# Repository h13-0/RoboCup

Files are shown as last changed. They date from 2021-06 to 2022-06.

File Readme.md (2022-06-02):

# RoboCup 2021 助老机器人赛道
中国机器人大赛国一(冠军)实现。  
由于本文档中有较多图片注释, 因此国内用户阅读本文档时应注意使用上网工具后再进行阅读。  
# 获奖证书
<details>
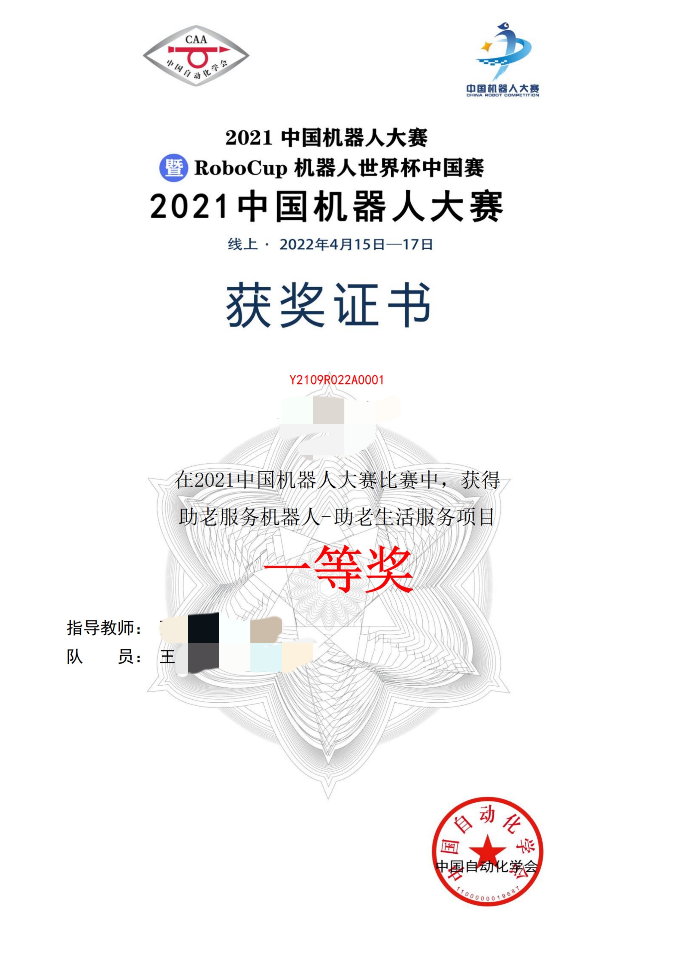
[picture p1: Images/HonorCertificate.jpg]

</details>

# 使用本仓库
如果需要更改代码, 则建议直接fork本仓库。  
## 克隆建议:
由于本仓库已经拆分出多个子模块, <strong><font color='red'>直接下载zip会造成缺少子模块的情况。</font></strong>  
如需复现本项目, 则<strong><font color='red'>必须</font></strong>使用git完成。  
git clone时需使用以下命令:  
```Powershell
git clone https://github.com/h13-0/RoboCup.git
git submodule update --init
```

# 渲染图
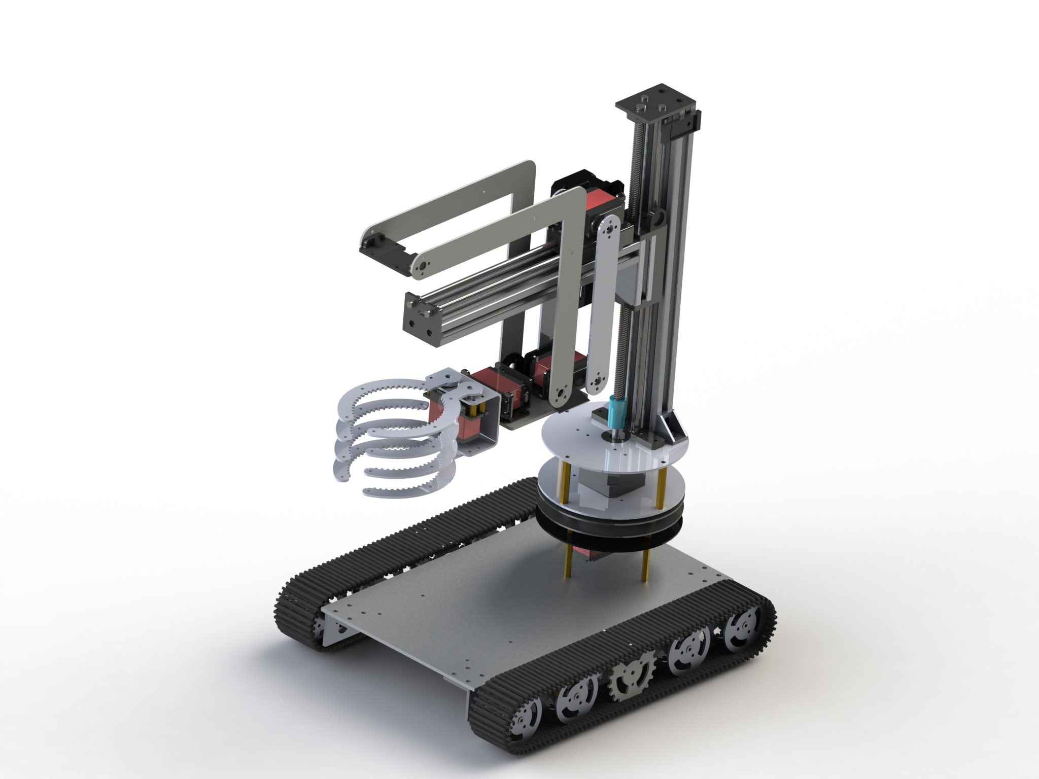
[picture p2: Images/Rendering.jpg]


# 项目构成
本项目主要分为三个板块:  
1. STM32板块
2. 图像处理板块
3. 机械设计

## STM32板块
参考:  
[STM32](./STM32/)  

## 图像处理板块
参考:  
[图像处理](./ImageProcessing)  

## 机械设计
参考:  
[机械设计](./Machine/)

## 上位机调参
上位机使用[VOFA+](https://www.vofa.plus/)
配置文件见[VOFAConfig](/HostComputer/VOFAConfig/)

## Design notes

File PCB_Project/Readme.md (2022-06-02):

# PCB工程  
[机器人PCB](./RobotPCB)  
[Air724UG转接板](./Air724_Module)  
(Air724UG转接板的TX RX好像画反了)

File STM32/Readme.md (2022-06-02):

# STM32
本部分负责机器人除图像处理以外的所有流程控制部分。  
本程序采用LL库, 底层使用CubeMX生成, 其他层由CubeIDE编写。  
如需复现此项目, 请自行安装[STM32CubeMX](https://www.st.com/zh/development-tools/stm32cubemx.html)和[STM32CubeIDE](https://www.st.com/en/development-tools/stm32cubeide.html)。  

## 为什么不用STP和Keil?
Keil的编译器过于老旧, 在实际使用中遇到了一些BUG, 并且stp(标准库)不再支持STM32F7、STM32G0等新产品。  
而LL效率和stp相当甚至更优, 写法相似, 故迁移至LL进行编写。  

## 程序移植
你只需要重新实现 `Platform` 文件夹中全部的函数即可。  
即使你使用的是Hal库或者标准库, 只要STM32和C语言过关, 就不存在任何问题。  
~~即如果您无法从LL移植到Hal或者标库，不是本项目的问题。~~  

<details>
<summary>代码结构</summary>
程序分为应用层, 驱动层, 底层。各层之间解耦合。  
应用层只能通过 `Platform/ports.h` 调用驱动层。  
驱动层只能通过 `Platform/xx.h` 调用底层。  
为了考虑整体移植性, 降低了部分驱动层使用简洁性。  

如无特殊需求, 只需要修改 `App.c` 文件即可实现比赛全流程。  

程序结构:  
```
STM32:
│  .cproject 
│  .project                                 -> 项目文件, 使用STM32CubeIDE打开本文件即可。
│  STM32.ioc                                -> CubeMX配置文件, 使用CubeMX打开本文件进行底层配置。
│  STM32F103RCTX_FLASH.ld
│
├─Drivers                                   -> [ST库文件]
│  ├─CMSIS                                  -> [ST库文件] CMSIS
│  │
│  └─STM32F1xx_HAL_Driver                   -> [ST库文件] STM32的Hal和LL库文件
│
├─Images
│  ├─ChineseFonts                           -> [资源文件] 隶书汉字字模, 字模转换用
│  │      *.bmp
│  │
│  └─SchoolMotto                            -> [资源文件] 校训图, 字模转换用
│          SchoolMotto.bmp
│
├─Inc
│
├─Src
│  │  main.c
│  │  PrivateConfigs.h                      -> [配置文件] 隐私相关配置文件, 如电话号码, 已gitignore。
│  │  RobotConfigs.h                        -> [配置文件] 机器人全局配置文件。
│  │  stm32f1xx_hal_msp.c
│  │  stm32f1xx_it.c                        -> [中断管理] 中断表。
│  │  syscalls.c
│  │  sysmem.c
│  │  system_stm32f1xx.c
│  │
│  ├─App                                    -> [应用层]
│  │  │  App.c                              -> **比赛主要逻辑流程**
│  │  │  App.h
│  │  │
│  │  ├─AppLog                              -> Log库实现
│  │  │  │  AppLog.c
│  │  │  │  AppLog.h
│  │  │  │
│  │  │  └─JustFloat                        -> VOFA 上位机的 `JustFloat` 协议实现
│  │  │          JustFloat.c
│  │  │          JustFloat.h
│  │  │
│  │  ├─ArmControl                          -> 机械臂控制库
│  │  │      ArmControl.h
│  │  │      LiftingPlatform.c              -> 升降台机械臂控制实现
│  │  │      LiftingPlatform.h
│  │  │      MechanicalArm.c                -> 传统机械臂控制实现
│  │  │
│  │  ├─Debug
│  │  │  │  Debug.c                         -> 将串口中断信息整理到`ParameterAdjust`中
│  │  │  │  Debug.h
│  │  │  │
│  │  │  └─ParameterAdjust                  -> 参数调节器
│  │  │          ParameterAdjust.c
│  │  │          ParameterAdjust.h
│  │  │
│  │  ├─Examples                            -> [Examples] 本文件夹下为调用App、Driver、Platform层的函数Demo以及赛题要求的子步骤函数实现。
│  │  │      AllInit.c                      -> [赛题实现] 初始化所有软硬件的Demo
│  │  │      AllInit.h
│  │  │      AngleSensorTest.c              -> [Demo] 测试陀螺仪偏航角的实现
│  │  │      AngleSensorTest.h
│  │  │      BluetoothTest.c                -> [赛题实现] 赛题所要求的蓝牙相关功能
│  │  │      BluetoothTest.h
│  │  │      BroadcastIdentifyResult.c      -> 使用语音播报水果识别结果的实现
│  │  │      BroadcastIdentifyResult.h
│  │  │      CatchApple.c                   -> [赛题实现] 抓取苹果的实现
│  │  │      CatchApple.h
│  │  │      CatchTrashCan.c                -> [赛题实现] 抓取垃圾桶的实现
│  │  │      CatchTrashCan.h
│  │  │      DisplayResult.c                -> [赛题实现] 将识别结果显示在显示屏上的实现
│  │  │      DisplayResult.h
│  │  │      DisplaySchoolMotto.c           -> [赛题实现] 显示校训
│  │  │      DisplaySchoolMotto.h
│  │  │      EmptyTrash.c                   -> [赛题实现] 清空垃圾桶的实现
│  │  │      EmptyTrash.h
│  │  │      Examples.h                     -> [接口文件] 所有Example的头文件
│  │  │      IdentifyFruit.c                -> [赛题实现] 识别水果的实现
│  │  │      IdentifyFruit.h
│  │  │      PlaceApple.c                   -> [赛题实现] 放置水果的实现
│  │  │      PlaceApple.h
│  │  │      PlaceTrashCan.c                -> [赛题实现] 放置垃圾桶的实现
│  │  │      PlaceTrashCan.h
│  │  │      PrepareArmPosition.c           -> [赛题实现] 使机械臂进入准备状态
│  │  │      PrepareArmPosition.h
│  │  │      SendResultViaMessage.c         -> [赛题实现] 将识别结果通过短信发送到指定手机
│  │  │      SendResultViaMessage.h
│  │  │      ThrowApple.c                   -> [赛题实现] 扔苹果
│  │  │      ThrowApple.h
│  │  │      WashApple.c                    -> [赛题实现] 洗苹果
│  │  │      WashApple.h
│  │  │
│  │  ├─FastMatch                           -> [协议解析] 一个简单协议解析器
│  │  │      FastMatch.h
│  │  │
│  │  ├─MotionControl                       -> [运动控制] 运动控制实现
│  │  │      MotionControl.c
│  │  │      MotionControl.h
│  │  │
│  │  ├─PID                                 -> [PID] PID算法实现
│  │  │      PID.c
│  │  │      PID.h
│  │  │
│  │  ├─Timer                               -> [定时器] 系统框架定时器
│  │  │      Timer.c
│  │  │      Timer.h
│  │  │
│  │  ├─TOF
│  │  ├─UI                                  -> [UI] 简单UI实现
│  │  │      DrawPicture.c                  -> 绘制图像
│  │  │      DrawPicture.h
│  │  │      DrawText.c                     -> 绘制文本
│  │  │      DrawText.h
│  │  │      OfficialScriptChineseFont.c    -> 隶书汉语字体库
│  │  │      OfficialScriptChineseFont.h
│  │  │      SchoolMotto.c                  -> 校训图片库
│  │  │      SchoolMotto.h
│  │  │      UI.h                           -> UI接口文件
│  │  │
│  │  └─VoicePlayer                         -> [VoicePlayer] 语音播报框架
│  │          VoicePlayer.c
│  │          VoicePlayer.h
│  │
│  ├─Drivers                                -> [驱动层]
│  │  │  Drivers.c                          -> 驱动层初始化API实现
│  │  │  Drivers.h
│  │  │
│  │  ├─Bluetooth                           -> [Driver] HC-05蓝牙驱动
│  │  │      Bluetooth.c
│  │  │      Bluetooth.h
│  │  │
│  │  ├─DF_PlayerMini                       -> [Driver] DF Player Mini 语音播放器驱动
│  │  │      DF_PlayerMini.c
│  │  │      DF_PlayerMini.h
│  │  │
│  │  ├─Encoder                             -> [Driver] 编码器驱动
│  │  │      Encoder.c
│  │  │      Encoder.h
│  │  │
│  │  ├─ImageProcessingModule               -> [Driver] 图像处理模块驱动(即协议解析器)
│  │  │      ImageProcessingModule.c
│  │  │      ImageProcessingModule.h
│  │  │
│  │  ├─INA219                              -> [Driver] INA219电流传感器驱动
│  │  │      INA219.c
│  │  │      INA219.h
│  │  │
│  │  ├─Luat                                -> [Driver] Air724UG 4G 模块AT驱动
│  │  │      Luat.c
│  │  │      Luat.h
│  │  │
│  │  ├─Motor                               -> [Driver] H桥电机驱动板驱动
│  │  │      Motor.c
│  │  │      Motor.h
│  │  │
│  │  ├─Servo                               -> [Driver] 舵机驱动
│  │  │      Servo.c
│  │  │      Servo.h
│  │  │
│  │  ├─SimpleProtocolPraise                -> [Driver] 简单协议解析器
│  │  │      SimpleProtocolPraise.h
│  │  │
│  │  ├─SKTOF                               -> [Driver] SK TOF 驱动
│  │  │      SKTOF.c
│  │  │      SKTOF.h
│  │  │
│  │  ├─SSD1283                             -> [Driver] SSD1283 屏幕驱动
│  │  │      SSD1283.c
│  │  │      SSD1283.h
│  │  │
│  │  ├─Stepper                             -> [Driver] 步进驱动
│  │  │      Stepper.c
│  │  │      Stepper.h
│  │  │
│  │  ├─VL6180X                             -> [Driver] VL6180X 短距离TOF 驱动
│  │  │  ├─Core
│  │  │  │      vl6180x_api.c
│  │  │  │      vl6180x_api.h
│  │  │  │      vl6180x_cfg.h
│  │  │  │      vl6180x_def.h
│  │  │  │      vl6180x_i2c.c
│  │  │  │      vl6180x_i2c.h
│  │  │  │
│  │  │  └─Platform
│  │  │          vl6180x_easy_api.c         -> [Driver] VL6180X 驱动简易接口实现
│  │  │          vl6180x_easy_api.h
│  │  │          vl6180x_platform.c
│  │  │          vl6180x_platform.h
│  │  │          vl6180x_types.h
│  │  │
│  │  └─WT101                               -> [Driver] WT101 陀螺仪 驱动
│  │          WT101.c
│  │          WT101.h
│  │
│  └─Platform                               -> 底层, 用于适配LL库。如果想要移植到Hal库或标准库, 请关注本文件夹。
│      │  ports.c                           -> [Platform] 底层初始化API实现
│      │  ports.h
│      │
│      ├─Clock                              -> [Platform] 系统时钟实现。
│      │      Clock.c
│      │      Clock.h
│      │      Readme.md
│      │
│      ├─EncoderPorts                       -> [Platform] 编码器底层接口。
│      │      Encoder.md
│      │      EncoderPorts.c
│      │      EncoderPorts.h
│      │
│      ├─GPIO                               -> [Platform] GPIO底层接口。
│      │      GPIO.c
│      │      GPIO.h
│      │
│      ├─I2C                                -> [Platform] I2C底层接口。
│      │      I2C.c
│      │      I2C.h
│      │
│      ├─Interrupts                         -> [Platform] 中断底层接口。
│      │  │  Interrupts.h
│      │  │
│      │  ├─ExternalInterrupts              -> [Platform] 外部中断
│      │  ├─TimerInterrupts                 -> [Platform] 定时器中断
│      │  │      TimerInterrupts.c
│      │  │      TimerInterrupts.h
│      │  │
│      │  └─USARTInterrupts                 -> [Platform] 串口中断
│      │          USARTInterrupts.c
│      │          USARTInterrupts.h
│      │
│      ├─PWM                                -> [Platform] PWM底层实现
│      │      PWM.c
│      │      PWM.h
│      │
│      ├─SPI                                -> [Platform] SPI底层实现
│      │      SPI.c
│      │      SPI.h
│      │
│      └─USART                              -> [Platform] 串口底层实现
│              USART.c
│              USART.h
│
├─Startup
│      startup_stm32f103rctx.s
│
└─Voices                                    -> [资源文件] 语音播报原素材, 请使用本文件下的素材文件进行播报。
        00*.mp3
```
</details>

# 电路图  
[电路图](../PCB_Project/)  

# 硬件选择
如您需要复现本项目, 建议使用STM32F103RC以上的型号, 由于串口数量原因, 不建议使用本项目所使用的的STM32F103RCT6。  
本项目所有重要模块的开发文档均已上传至[Docs](../Docs/)  
## 陀螺仪
陀螺仪选型为WT101, 经过测试, MPU9250不满足需求。  

## 激光测距
### 主激光
SK-Z-20 串口激光测距。  
### 机械臂闭环激光
由于本结构机械臂坐标系解算控制精度已达标, 因此项目中未使用, 推荐VL6180X。  

## 显示屏
SSD1283半反半透屏, 特性是阳光下清晰可见。  

## 4G模块
[合宙Air724UG](https://www.openluat.com/product_center/product_detail?id=12)  
2020年年初价格: 19.9元一张核心板一张开发板。  

## 电流检测
通过检测机械爪舵机电流来检测机械爪是否成功抓到物体。  
可以使用图像识别模块代替, 本项目中未使用。  

## 蓝牙模块
HC-05  

## 电机驱动(H桥)
298NAD  

## 电机
1:30减速比, 100线正交光电码盘, 转速280。  

## 定时器  
定时器选择请参考STM32CubeMX配置文件。  

## 舵机
舵机命名参考: 
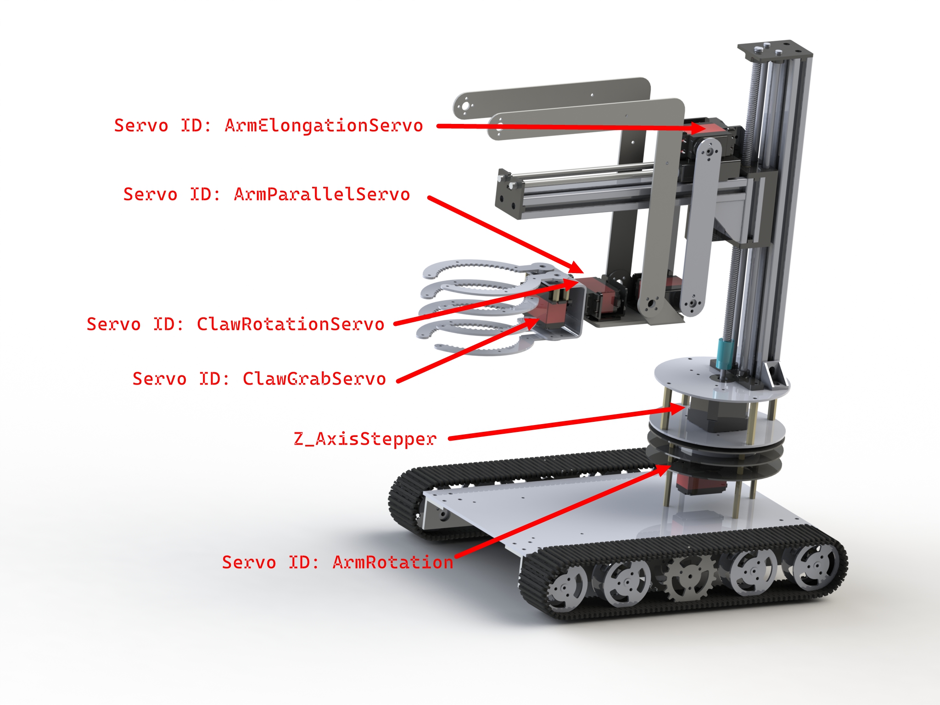
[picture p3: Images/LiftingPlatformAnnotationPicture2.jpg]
  
舵机选型(以`LiftingPlatform`为准):  
| Servo ID | Model |  
| --- | --- |
| ArmRotationServo | TD8120MG 270° |  
| ArmElongationServo | DS3235MG 180° |  
| ArmParallelServo | DS3230MG 180° |  
| ClawRotationServo  | TD8120MG 180° |  
| ClawGrabServo | TBSN-K15 180° |  

> Note:  
> MG为数字舵机, SG为模拟舵机。  

## 串口调参
接口: USART1  
波特率: 1152000  
上位机使用[VOFA+](https://www.vofa.plus/)  
参考: [HostComputer](../HostComputer/VOFAConfig/Readme.md)  

### 图像处理模块  
使用RK3328+RK1808S0计算棒, 推荐替换为RK3568.  
#### 图像处理部分参考    
[图像处理](../ImageProcessing/Readme.md)  
[通信协议](../ImageProcessing/Protocol.md)

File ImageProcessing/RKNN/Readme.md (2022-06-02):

# 程序架构
文件结构:  
```
RKNN/Code:
│  Logo.jpg
│  
│  Readme.md
│
├─FrameBufferMonitor
│
├─Images
│
├─TargetDetector
│
├─WorkingFlow
│
└─YoloDetector
```

`Logo.jpg`           为启动时显示的Logo  
`main.py`            为入口函数, 随后调用`WorkingFlow/MainWorkingFlow.py`  
`FrameBufferMonitor` 将图像越过Linux的UI层直接输出到屏幕的代码实现, **注意不能使用桌面模式，只能使用命令行模式(即initlevel为3而不是5)**  
`Images`             程序STM32控制程序拍照后, 图片保存的目录  
`TargetDetector`     基于HSV的靶标检测  
`WorkingFlow`        主要工作流程实现  
`YoloDetector`       RKNN的YOLO V4 Tiny实现  

## FrameBufferMonitor
具体linux的`FrameBuffer`是什么请自行百度。  
该实现使用C++和Python混合编程, C++实现详见对应src文件夹。  
如果项目所提供的[libframebuffer.so](./Code/FrameBufferMonitor/lib/libframebuffer.so)无法使用, 请自行搭建`OpenCV`环境重新编译。  
```Bash
cd ImageProcessing/RKNN/Code/FrameBufferMonitor
chomd 777 ./build.sh
./build.sh
```
如遇到错误, 请自行检查OpenCV环境。  

### 调用方式
比较简单, 建议直接查看[FrameBufferMonitor.py](./Code/FrameBufferMonitor/FrameBufferMonitor.py)源码。  

## Images
文件命名方式: `时间戳.jpg`。  
本功能是为了方便调节靶标的HSV色域提供的方法。  
在STM32程序中的[PlaceApple.c](../../STM32/Src/App/Examples/PlaceApple.c#L112)中有所调用。  
`STM32/Src/App/Examples/PlaceApple.c Line 112`
```C
TakeSnapShot();
```

## TargetDetector
本方案采用HSV进行实现。  
为方便调参, 本项目实现了一个HSV调参工具: [HSV_Range](https://github.com/h13-0/HSV-Range)  
参数较为简单, 建议直接阅读源码: [TargetDetector.py](./Code/TargetDetector/TargetDetector.py)  
值得注意的是, 本参数仅适用于固定的靶标和**固定的分辨率(640, 320)**  

## WorkingFlow
参数较多但简单, 看源码吧。  

## YoloDetector
模型文件需要从`Darknet`转换到`rknn`, 参考: [tools](../YoloV4Tiny/tools/Readme.md)  

# 环境配置
有以下几种方案(按推荐顺序排序):  
1. [RKNN_Lite](https://github.com/rockchip-linux/rknn-toolkit/tree/master/rknn-toolkit-lite/packages)
2. [直接使用Archiconda部署](./Environment/RK3328_env/Readme.md)
3. [ROC-RK3328-CC镜像部署](./Environment/ROC-RK3328-CC-Images/Readme.md)

本文件夹下所有文件的下载链接:  
> 链接：https://pan.baidu.com/s/1-s8oynvUIC-BW_bOgdHDag?pwd=heop  
> 提取码：heop

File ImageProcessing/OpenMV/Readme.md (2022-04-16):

**已废弃, 不要使用。 建议使用YoloV4Tiny.**

# OpenMV水果识别部分

## 串口通信
### STM32 -> OpenMV
```

```

### OpenMV -> STM32
```

import struct
usart = UART(3, 115200)
msgPack = struct.pack("<ffbbbb", float((r[0] + r[2]) / 400.0), float((r[1] + r[3]) / 240.0), 0x00, 0x00, 0x80, 0x7f)
usart.write(msgPack)
```

## Cascade级联分类器实现

### 制作数据集

### 打包数据集
```
opencv_createsamples.exe -info E:\project\RoboCup\OpenMV\CascadeClassifier\Resized\Apple\List.txt -vec apple.vec -bg E:\project\RoboCup\OpenMV\CascadeClassifier\Background\List.txt -num 151 -w 32 -h 32
```

### 训练
```
mkdir xml
C:\Users\h13\Documents\OpenCVCascade\opencv_traincascade.exe -data xml -vec .\apple.vec -bg E:\project\RoboCup\OpenMV\CascadeClassifier\Background\List.txt -numPos 120 -numNeg 151 -numStages 17 -featureType haar -w 32 -h 32
```

### 转换二进制文件
```
python.exe .\cascade_convert.py .\cascade.xml
```

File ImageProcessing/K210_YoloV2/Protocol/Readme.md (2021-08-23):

# Usage
Copy Floder `` to Disk
```
from Protocol.Protocol import BinaryProtocol
import time

protocol = BinaryProtocol(115200)

while True:
    packet = protocol.GetNewPacket()
    while(packet != None):
        p = protocol.MatchFloat(packet, "AP:")
        if(p != None):
            print(p)
        packet = protocol.GetNewPacket()
    time.sleep(0.5)
```

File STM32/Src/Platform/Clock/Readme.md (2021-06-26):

# CubeMX配置
System Core -> NVIC
    -> Code generation
        -> Time base: System tick timer
            -> Cancel "Call HAL handler" 

# 使用
1. 将 `void SysTickInterruptHandler(void)` 放到 `stm32f1xx_it.c` 中的 `void SysTick_Handler(void)` 中。
2. 调用 `ClockInit()` 。

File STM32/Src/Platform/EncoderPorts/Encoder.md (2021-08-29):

# CubeMX配置
TIMx -> Combined Channels -> Encoder Mode
     -> Parameter Settings -> Encoder -> Encoder Mode -> Encoder Mode Tl1 (只记录上升沿)
                                      -> Polarity -> Rising Edge

GPIO -> TIM -> PXx -> GPIO Pull-up/Pull-down -> Pull-down

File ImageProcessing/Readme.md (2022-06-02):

# 水果种类  
1. 苹果
2. 香梨
3. 橘子
4. 雪梨
5. 柠檬
6. 桃子
7. 香蕉
8. 火龙果
9. 猕猴桃
水果模型图参考[水果模型](../Docs/2021%E4%B8%AD%E5%9B%BD%E6%9C%BA%E5%99%A8%E4%BA%BA%E5%A4%A7%E8%B5%9B-%E5%8A%A9%E8%80%81%E6%9C%8D%E5%8A%A1%E6%9C%BA%E5%99%A8%E4%BA%BA(%E5%8A%A9%E8%80%81%E7%94%9F%E6%B4%BB%E6%9C%8D%E5%8A%A1)-%E6%B0%B4%E6%9E%9C%E6%A8%A1%E5%9E%8B.pdf)  

# 通信协议  
[Protocol](/ImageProcessing/Protocol.md)  

# 识别方案
## YoloV4Tiny
效果最好, 但是算力要求较高。  
建议部署于RK1808或RK3568等平台上。  
使用[Darknet](https://github.com/AlexeyAB/darknet)进行训练。  
可识别内容仅限于上述9种水果, 不包括靶标。  
靶标建议使用HSV色块识别。  
训练集:  
> 链接：https://pan.baidu.com/s/13T8VhDXatusKtdSlCLSglQ?pwd=kcy0  
> 提取码：kcy0  

## HSV色块识别  
**不建议用于水果识别, 可用于靶标识别**  
[HSV水果识别实现](./HSV/RoboCupImageProcessing/)  
HSV调参工具: [HSV-Range](https://github.com/h13-0/HSV-Range)  

# 最终方案  
使用YoloV4Tiny进行水果识别, 利用`RKNN_Lite`部署于RK1808计算棒上, HSV进行靶标识别。  
最终方案见: [RKNN](./RKNN/)

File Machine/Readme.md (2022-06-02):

# 渲染图
  

# 实拍图


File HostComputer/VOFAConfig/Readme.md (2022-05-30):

# 上位机文档
上位机使用[VOFA+](https://www.vofa.plus/)  
UI配置文件, 命令配置文件均在本文件夹下, 请自行研究。

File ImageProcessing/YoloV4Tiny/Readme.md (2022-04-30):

# 炼丹方法
取海量残次丹药置于炉内, 水入洗之, 置于器内熬至百沸。  
再取结晶之物, 置于新炉, 加入上好佐料, 文火慢炖, 则丹药始成。  

<details>
<summary>详细做法</summary>
下载并解压[数据集](/http)  
先使用自动打标生成的数据集`yolomark`(由于数据集分布和实际情况有所出入, 且训练集验证集分布过于相似导致严重过拟合, 所以直接训练下来的模型的种类识别几乎完全错误, 但是方框是准的)  
然后保留自动打标生成的模型使用实际手动拍摄制作的数据集`yolomarkRealScene`再次进行训练即可。  

</details>

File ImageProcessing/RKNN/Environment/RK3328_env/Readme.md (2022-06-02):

# RK3328 RKNN_Lite 环境  
## 安装方法  
**可能**只能在[Firefly的ROC-RK3328-CC](https://www.t-firefly.com/product/rocrk3328cc.html)板子的[Ubuntu18.04](https://www.t-firefly.com/doc/download/34.html#other_68)的`ROC-RK3328-CC-UBUNTU18.04-GPT-20200730-1744.img`系统上使用，其他aarch64的Ubuntu18.04等系统上**可能**也可以使用，具体取决于`GLIBC`等系统底层依赖版本。  
**尽量将Archiconda安装到**`/opt/Archiconda/`下，然后将本文件夹解压到`/opt/Archiconda/RKNN_Lite`下，然后按照百度加载环境即可。  

`archiconda_RKNN_Lite.7z`下载链接:  
> 链接：https://pan.baidu.com/s/1-s8oynvUIC-BW_bOgdHDag?pwd=heop  
> 提取码：heop

## 使用方法
参考文档：[RKNN](../../Readme.md)

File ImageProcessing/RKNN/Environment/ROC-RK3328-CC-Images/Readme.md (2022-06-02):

# ROC-RK3328-CC镜像备份
## 使用方法
购买[ROC-RK3328-CC](https://www.t-firefly.com/product/rocrk3328cc.html)和[RK1808S0](https://t.rock-chips.com/portal.php?mod=view&aid=28), 使用[balenaEtcher](https://www.balena.io/etcher/)将`ROC-RK3328-CC.7z`刷入大于等于16G的内存卡中即可使用。  

## 下载链接
`ROC-RK3328-CC.7z`下载链接:  
> 链接：https://pan.baidu.com/s/1-s8oynvUIC-BW_bOgdHDag?pwd=heop  
> 提取码：heop

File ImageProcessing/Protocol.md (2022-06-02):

# 通信协议  
**物理接口采用串口, 波特率115200, 建议配合DMA使用**  

基础协议为二进制小端通信, 基础协议结构:  
`${Key}:${HexValue}`  
**`${HexValue}` 表示小端模式的二进制信息。**  

## 协议表:  
### STM32 -> Module:  
#### 命令  
Key = `CMD`  
Type = string  
| Key | Value | 作用 |
| --- | --- | --- |
| CMD | `AppleDetectLeft` | 检测左侧水果 |
| CMD | `FruitIdentify` | 检测水果数量和种类 |
| CMD | `TargetDetection` | 检测靶标位置 |

### Module -> STM32:  
#### 工作模式  
Key = `WM`  
Type = uint8_t  
| Value | Mode |
| ----- | --- |
| 0 | Standby |
| 1 | AppleDetectMax |
| 2 | AppleDetectLeft  |
| 3 | AppleDetectRight |
| 4 | TargetDetection  |
| 5 | FruitIdentify |
| 6 | SnapShot |

#### 苹果坐标输出  
Key = `AppCenX`  
Type = float  
Key = `AppCenY`  
Type = float  

| Key | Value | 作用 |
| --- | ----- | --- |
| `AppCenX` | 0~1 | AppCenX |
| `AppCenY` | 0~1 | AppCenY |

#### 靶标坐标输出  
Key = `TarCenX`  
Type = float  
Key = `TarCenY`  
Type = float  

| Key | Value | 作用 |
| --- | ----- | --- |
| `TarCenX` | 0~1 | TarCenX |
| `TarCenY` | 0~1 | TarCenY |

#### 水果种类输出  
Type = uint8_t  
| Key | Value | 作用 |
| --- | --- | --- |
| `AppleNum` | [1, QuantityLimit] | Number |
| `BananaNum` | [0, QuantityLimit] | |
| `KiwiFruitNum` | [0, QuantityLimit] | |
| `LemonNum` | [0, QuantityLimit] | |
| `OrangeNum` | [0, QuantityLimit] | |
| `PeachNum` | [0, QuantityLimit] | |
| `PearNum` | [0, QuantityLimit] | |
| `PitayaNum` | [0, QuantityLimit] | |
| `SnowPearNum` | [0, QuantityLimit] | |
| `FruitDetectFinished` | 0 ~ 1 | 1 -> Finished |

| Key | Value | Effect |
| --- | ----- | --- |
| `FruCenX` | 0~1 | Focus of all fruits |
| `FruCenY` | 0~1 | |

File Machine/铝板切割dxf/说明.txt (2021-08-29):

机械臂杆件140mm            2件
舵机云台中心圆盘转大圆盘顶盘 1件
舵机云台中心圆盘转大圆盘底盘 1件
摄像头支架                 2件
机械臂连接板               1件

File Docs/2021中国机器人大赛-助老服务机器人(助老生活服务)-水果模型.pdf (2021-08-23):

注：①该尺寸为人工测量，可能在一定范围内存在误差，仅供参考，具体尺寸 数据以比赛现场材料为准。
②本文档包含所有水果种类，比赛现场选用的水果种类及个数由当天临时 决定。
③用于完成“丢垃圾”动作的“吃剩苹果”模型为苹果模型随机挖去大约一 口的不规则形状，大致尺寸与苹果模型相同。
苹果

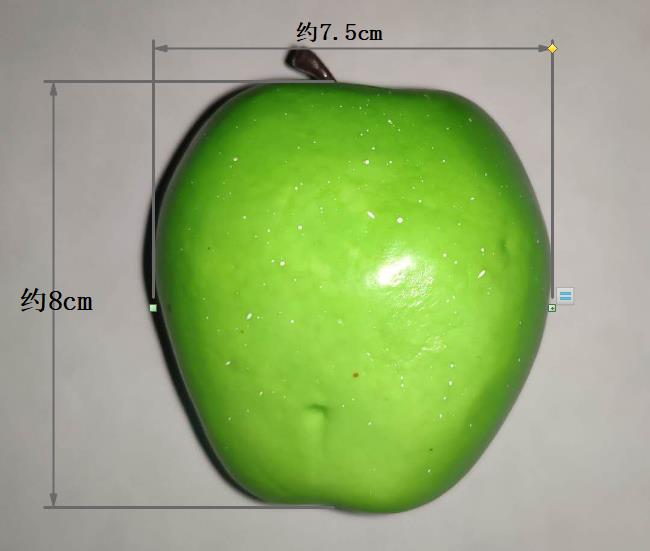
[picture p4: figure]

香梨

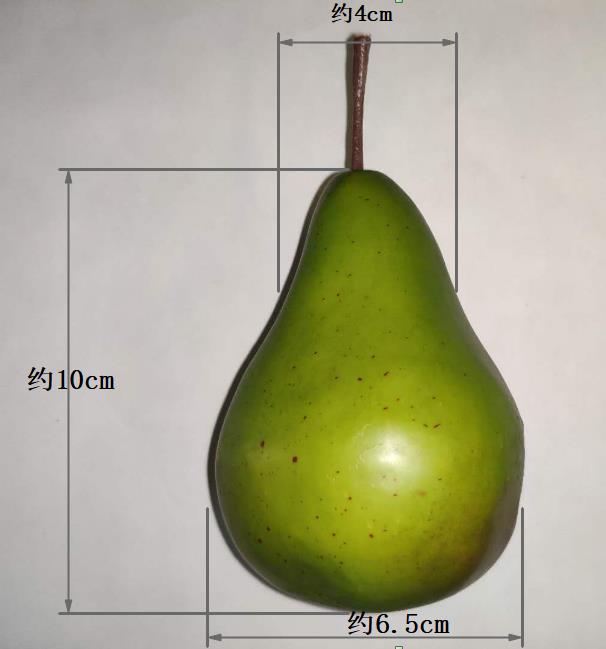
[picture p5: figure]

橘子

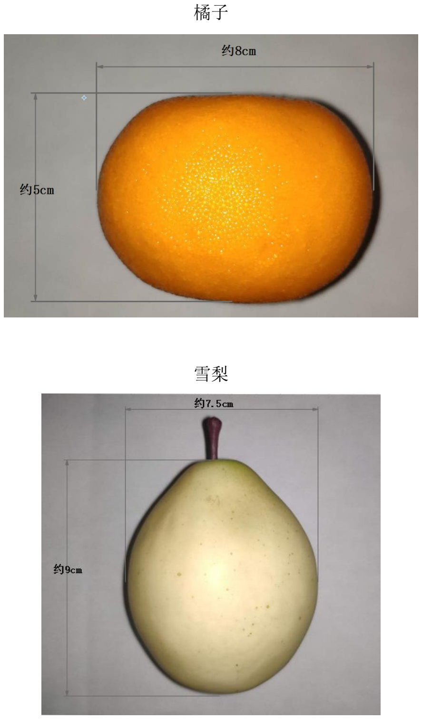
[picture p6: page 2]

雪梨

柠檬

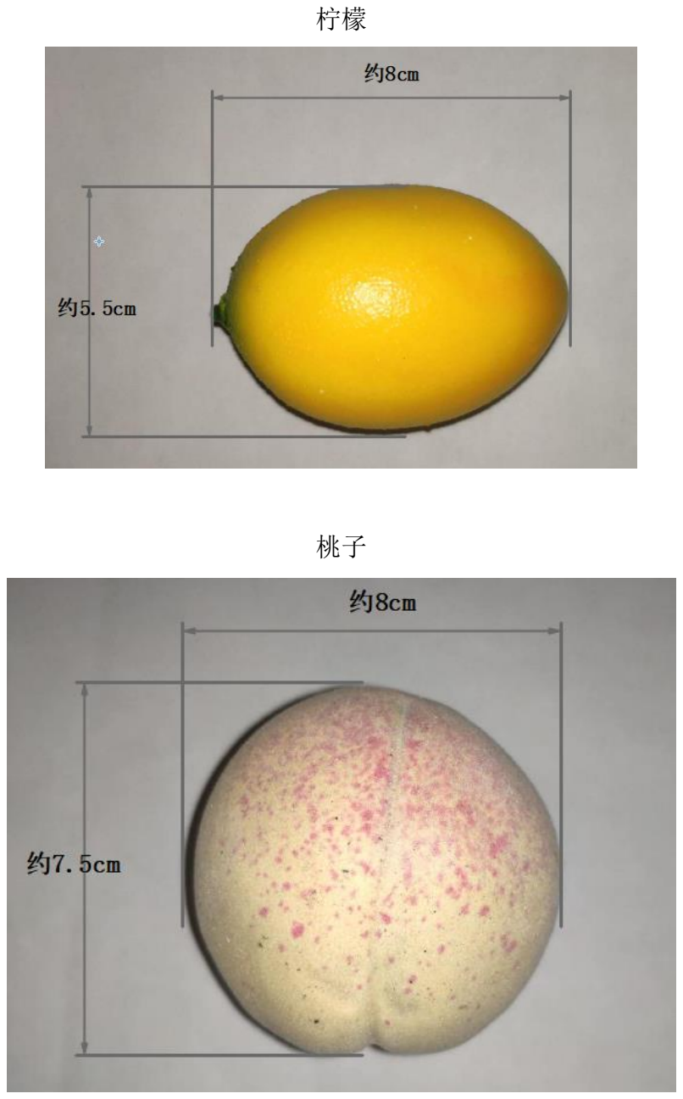
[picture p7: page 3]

桃子

香蕉

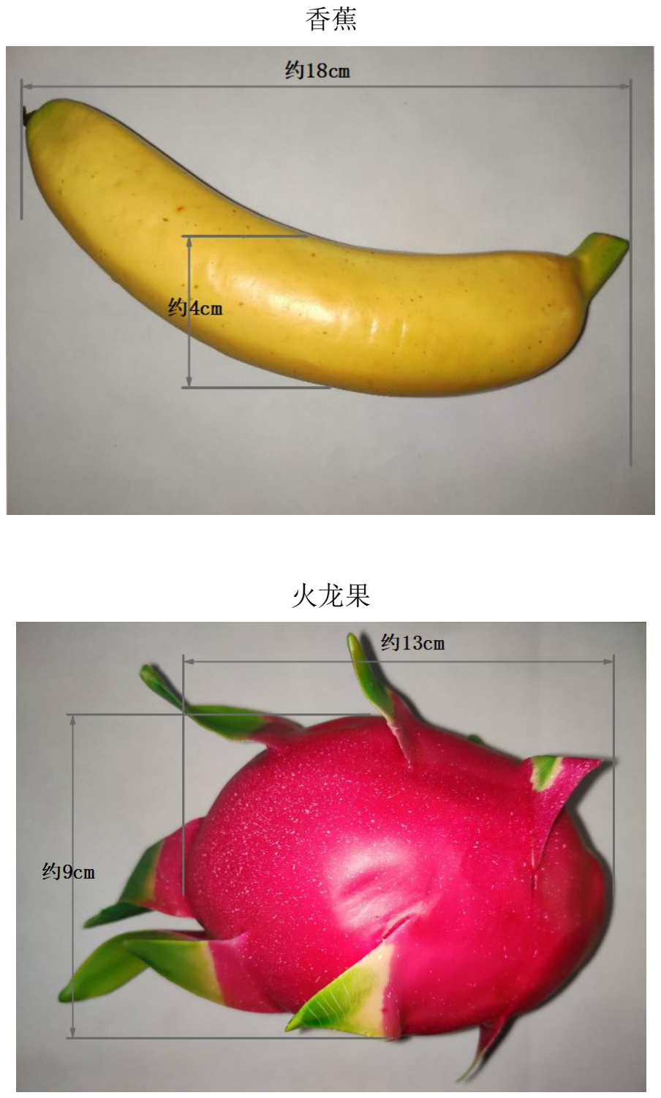
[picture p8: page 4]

## 火龙果

## 猕猴桃

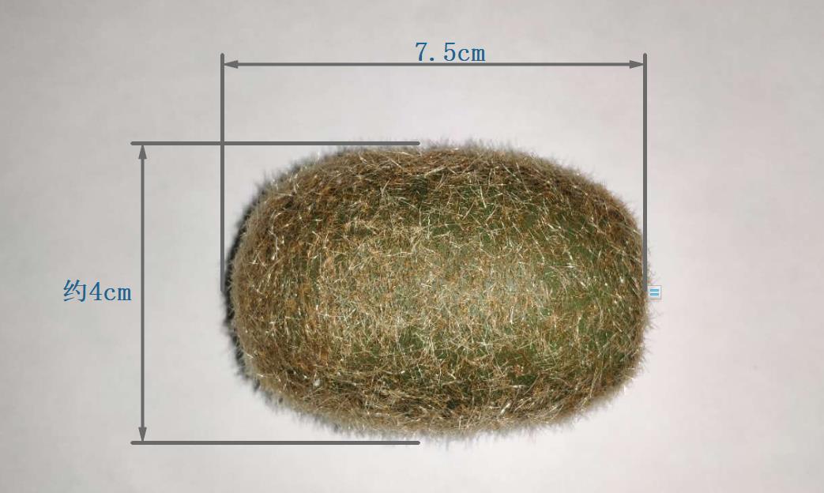
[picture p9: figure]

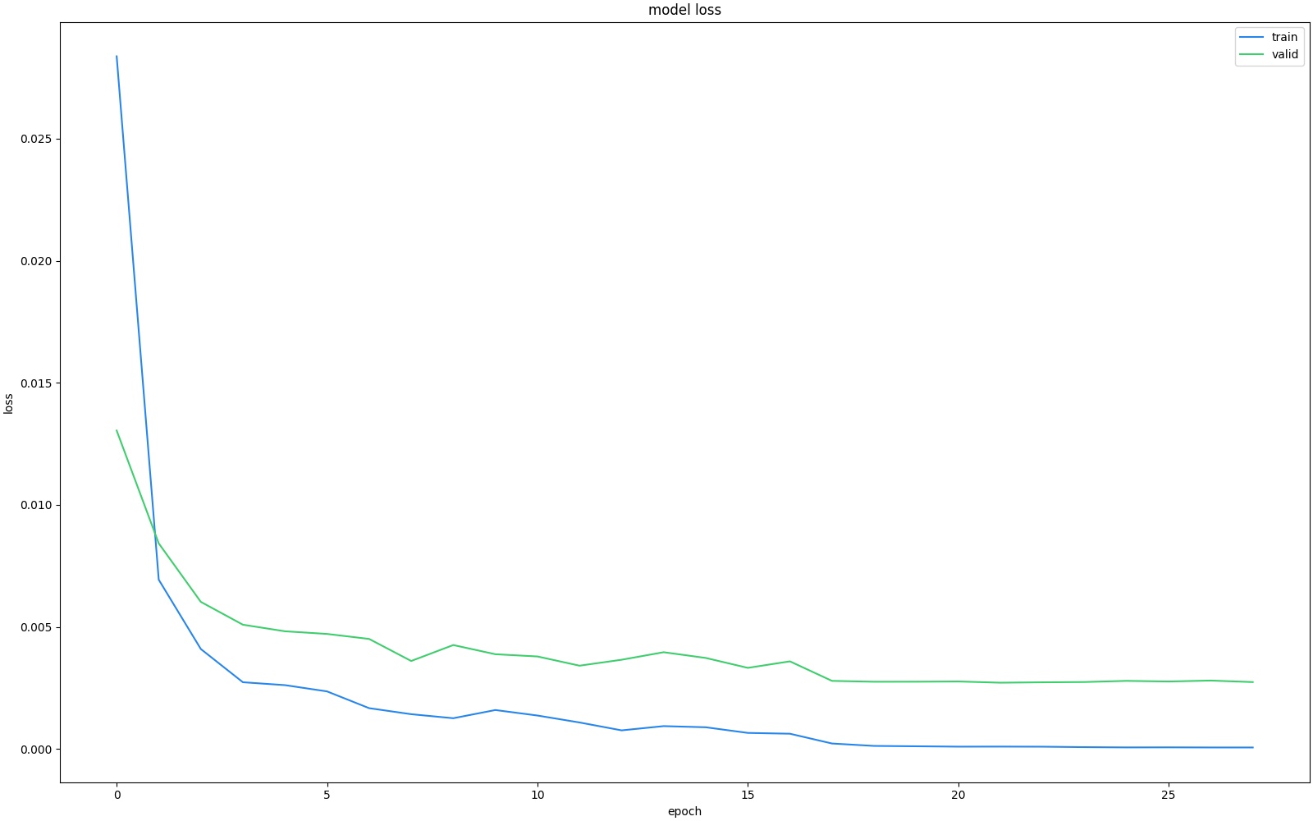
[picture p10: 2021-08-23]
ImageProcessing/K210_YoloV2/Examples/report.jpg

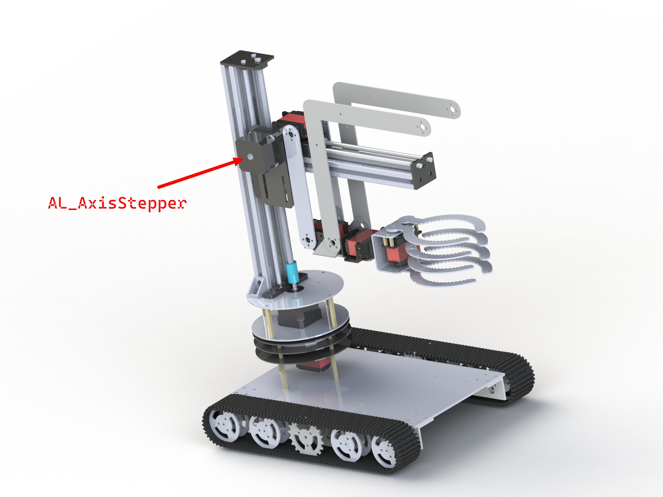
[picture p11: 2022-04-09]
Images/LiftingPlatformAnnotationPicture3.jpg

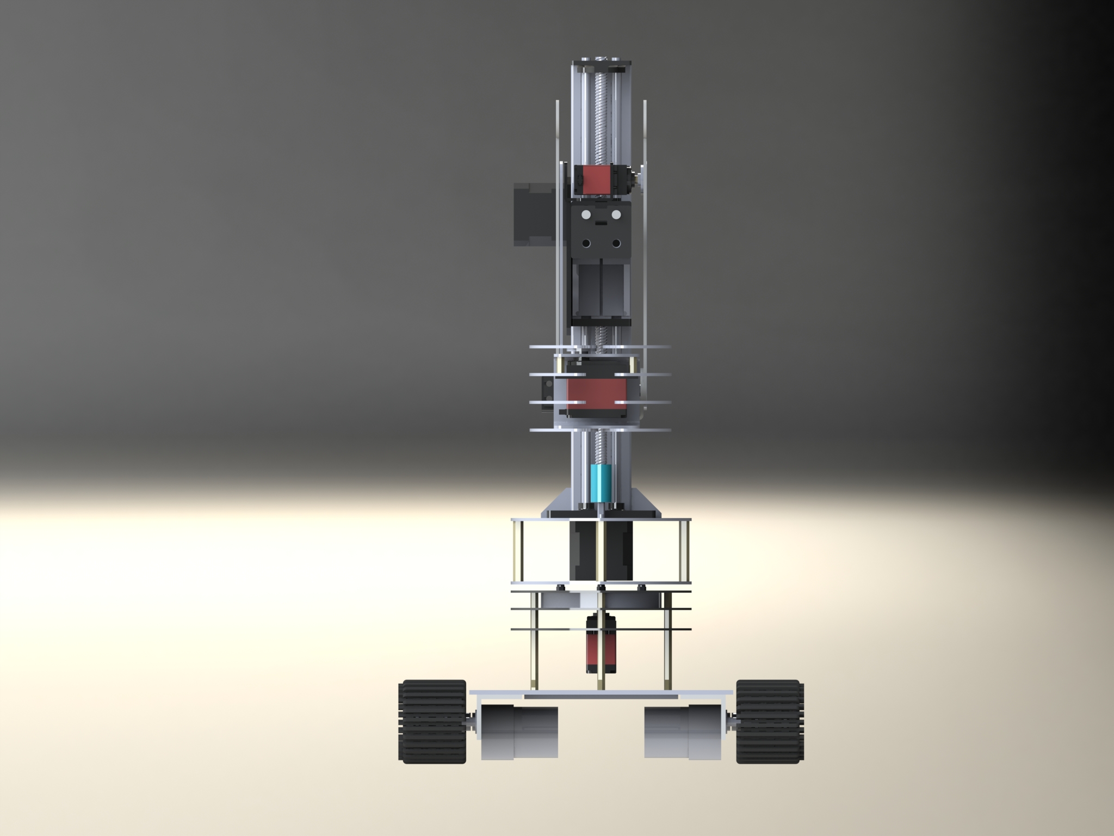
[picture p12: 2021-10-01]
Images/前视图.JPG

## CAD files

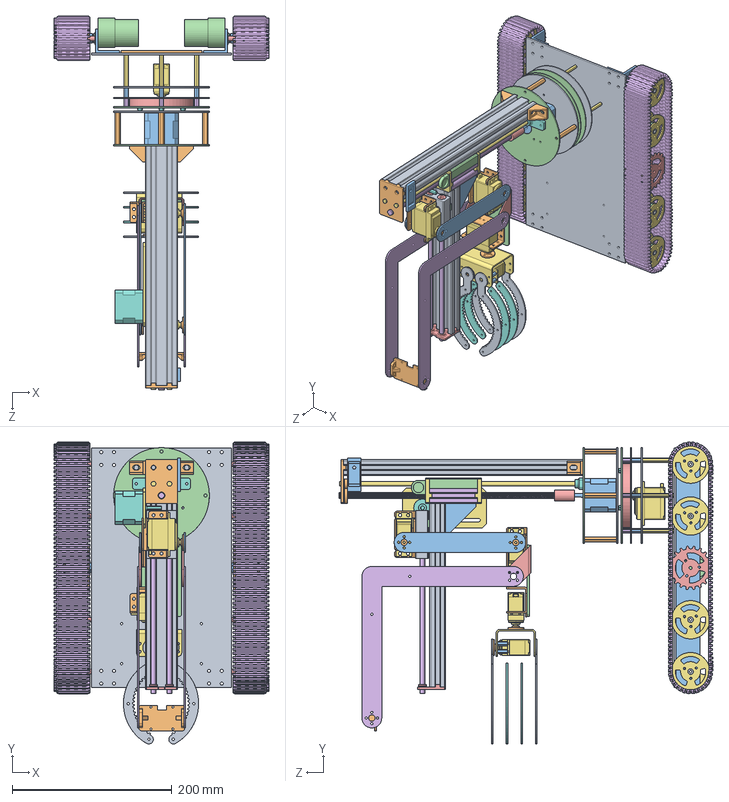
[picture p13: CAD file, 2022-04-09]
Machine/机器人总装图.SLDASM
269.0 x 378.5 x 468.5 mm
车板铝板
电池垫板
电机支架 x 2
M3铜柱17mm x 24
从动轮支杆 x 8
从动轮间隔杆 x 8
从动轮 x 16
M4大垫片 x 8
从动轮轴承 x 16
主动轮内齿轮 x 2
主动轮联轴器 x 2
3429电机 x 2
主动轮外齿轮 x 2
链条链节 x 256
舵机 x 5
舵机云台中心圆盘 x 2
舵机云台支架
舵机圆盘 x 5
M3铜柱12mm x 8
机械臂云台轴承支架 x 2
云台轴承
M3铜柱10mm x 4
M3铜柱39.5mm x 4
M3紧固螺丝 x 3
舵机云台中心圆盘转大圆盘底盘
M4铜柱40mm x 4
42步进40mm
舵机云台中心圆盘转大圆盘顶盘
5转8联轴器
8mmx4丝杆285mm
6mm滑杆307mm x 2
丝杆底支架
2040铝型材300mm
丝杆顶支架
8mm丝杆轴承
直线轴承支架
6mm滑杆直线轴承 x 8
铝型材2040x60mm
丝杆螺母支架 x 2
丝杆螺母 x 2
2040铝型材230mm
2020角件 x 2
2040角件 x 2
丝杆滑台内支架
丝杆滑台外支架
6mm滑杆220mm x 2
42步进支架
42步进35mm
丝杆滑块
舵机支架 x 3
机械臂杆件140mm x 2
机械臂连接板
舵机斜U支架
摄像头支架 x 2
机械爪基座
机械爪中间片 x 4
机械爪简化 x 4
摄像头连接座
霍尔传感器支架
磁铁竖向支架

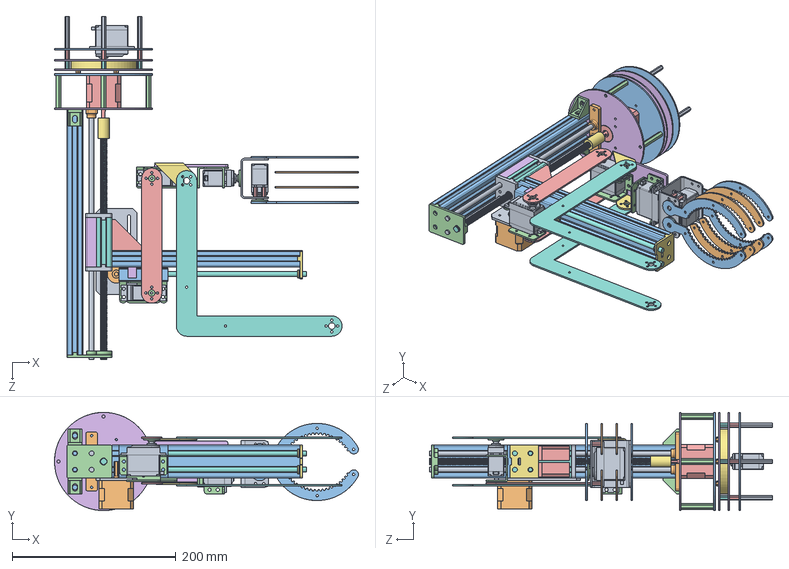
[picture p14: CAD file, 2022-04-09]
Machine/机械臂.SLDASM
371.4 x 120.0 x 419.5 mm
舵机 x 5
舵机云台中心圆盘 x 2
舵机云台支架
舵机圆盘 x 5
M3铜柱12mm x 8
机械臂云台轴承支架 x 2
云台轴承
M3铜柱10mm x 4
M3铜柱39.5mm x 4
M3紧固螺丝 x 3
舵机云台中心圆盘转大圆盘底盘
M4铜柱40mm x 4
42步进40mm
舵机云台中心圆盘转大圆盘顶盘
5转8联轴器
8mmx4丝杆285mm
6mm滑杆307mm x 2
丝杆底支架
2040铝型材300mm
丝杆顶支架
8mm丝杆轴承
直线轴承支架
6mm滑杆直线轴承 x 8
铝型材2040x60mm
丝杆螺母支架 x 2
丝杆螺母 x 2
2040铝型材230mm
2020角件 x 2
2040角件 x 2
丝杆滑台内支架
丝杆滑台外支架
6mm滑杆220mm x 2
42步进支架
42步进35mm
丝杆滑块
舵机支架 x 3
机械臂杆件140mm x 2
机械臂连接板
舵机斜U支架
摄像头支架 x 2
机械爪基座
机械爪中间片 x 4
机械爪简化 x 4

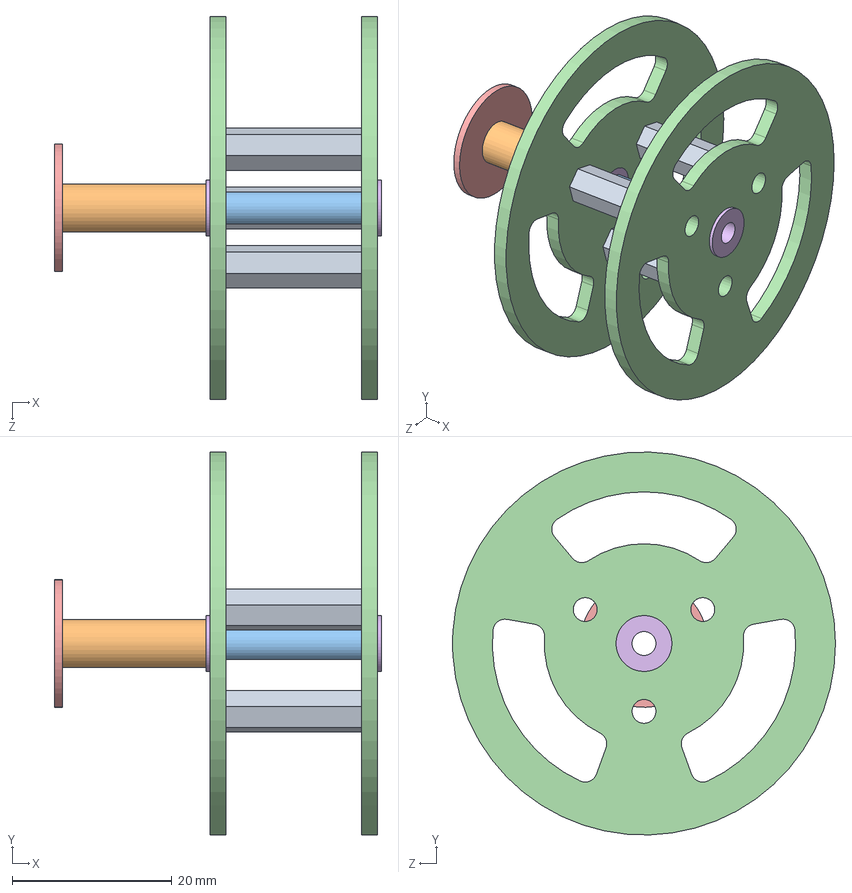
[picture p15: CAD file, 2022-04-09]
Machine/从动轮.SLDASM
41.0 x 48.0 x 48.0 mm
M3铜柱17mm x 3
从动轮支杆
从动轮间隔杆
从动轮 x 2
M4大垫片
从动轮轴承 x 2

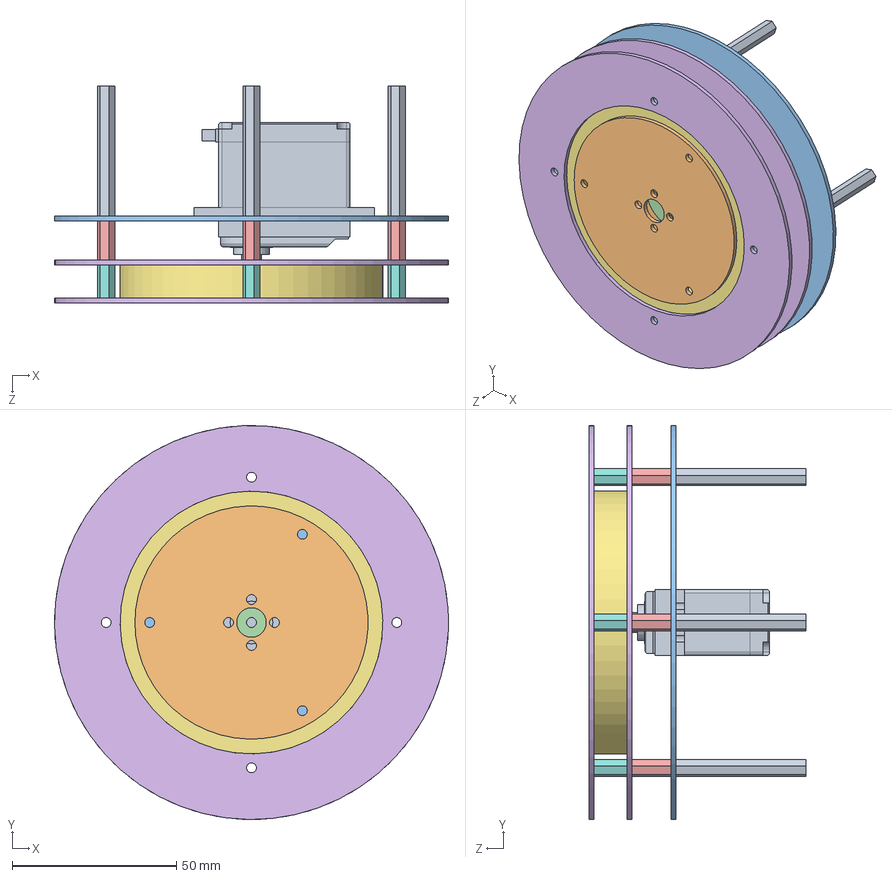
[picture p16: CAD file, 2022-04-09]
Machine/机械臂云台.SLDASM
120.0 x 120.0 x 66.0 mm
舵机
舵机云台中心圆盘 x 2
舵机云台支架
舵机圆盘
M3铜柱12mm x 4
机械臂云台轴承支架 x 2
云台轴承
M3铜柱10mm x 4
M3铜柱39.5mm x 4

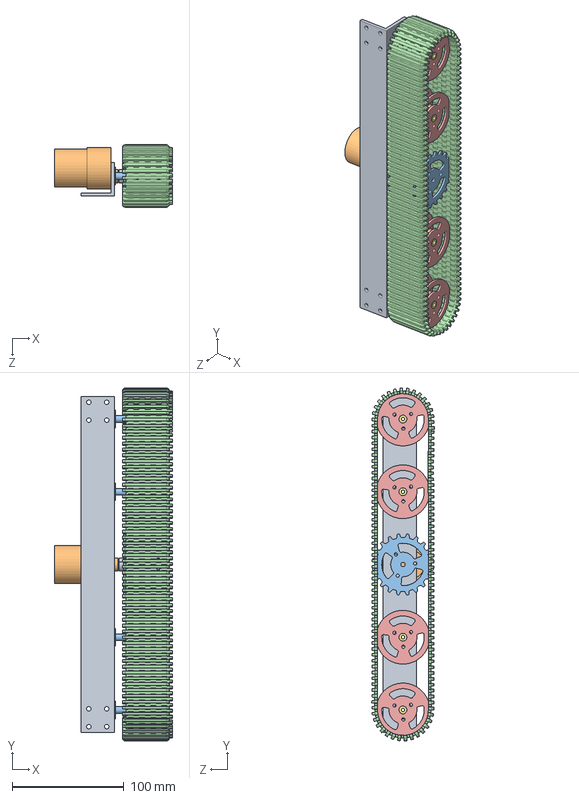
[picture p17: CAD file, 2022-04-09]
Machine/履带.SLDASM
105.9 x 315.5 x 55.9 mm
电机支架
M3铜柱17mm x 12
从动轮支杆 x 4
从动轮间隔杆 x 4
从动轮 x 8
M4大垫片 x 4
从动轮轴承 x 8
主动轮内齿轮
主动轮联轴器
3429电机
主动轮外齿轮
链条链节 x 128

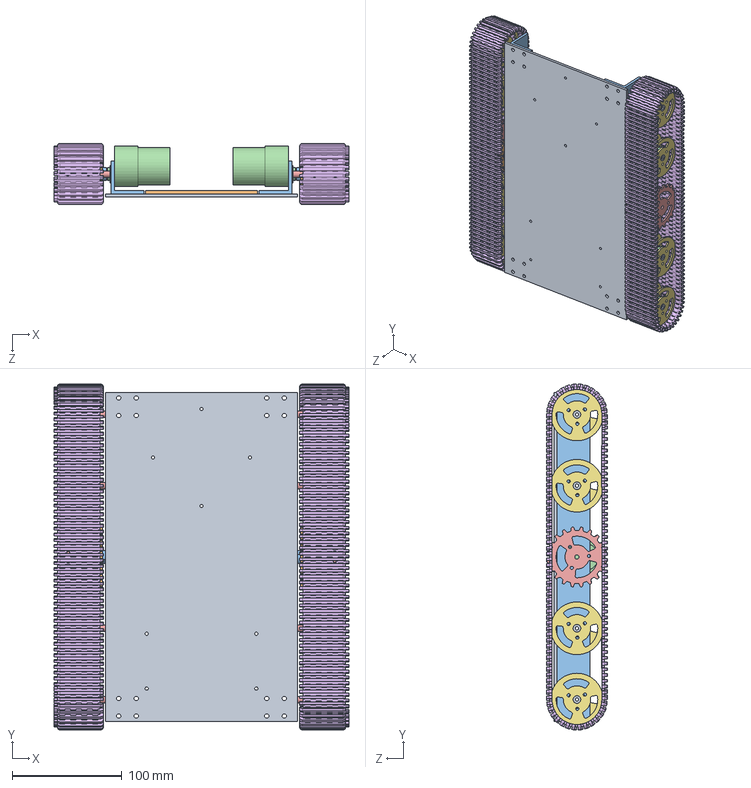
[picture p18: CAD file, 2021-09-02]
Machine/机器人底盘.SLDASM
269.0 x 315.5 x 55.9 mm
车板铝板
电池垫板
电机支架 x 2
M3铜柱17mm x 24
从动轮支杆 x 8
从动轮间隔杆 x 8
从动轮 x 16
M4大垫片 x 8
从动轮轴承 x 16
主动轮内齿轮 x 2
主动轮联轴器 x 2
3429电机 x 2
主动轮外齿轮 x 2
链条链节 x 256

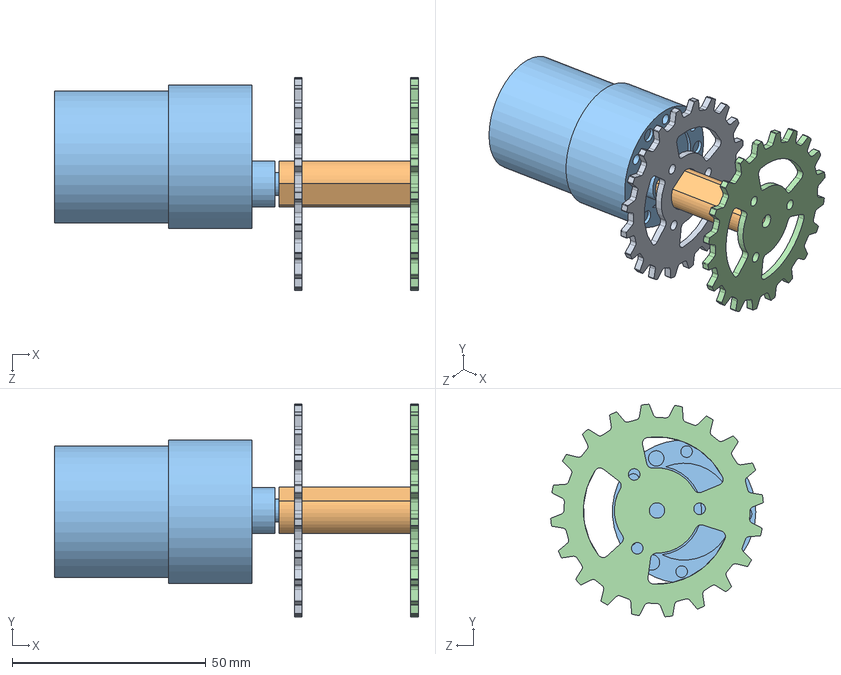
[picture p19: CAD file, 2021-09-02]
Machine/主动轮.SLDASM
93.9 x 54.8 x 54.8 mm
主动轮内齿轮
主动轮联轴器
3429电机
主动轮外齿轮

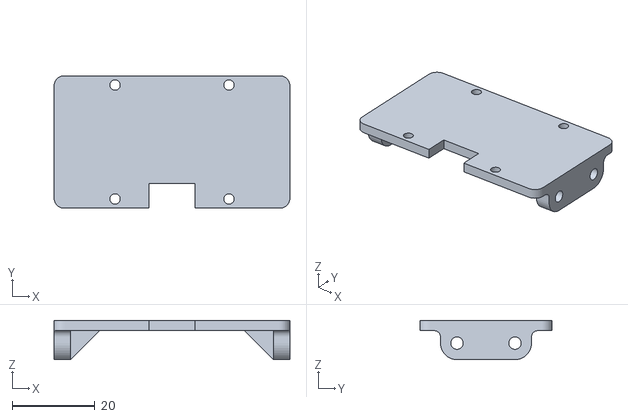
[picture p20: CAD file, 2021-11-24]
Machine/3D打印STL/摄像头连接座.STL
57.0 x 32.0 x 9.50

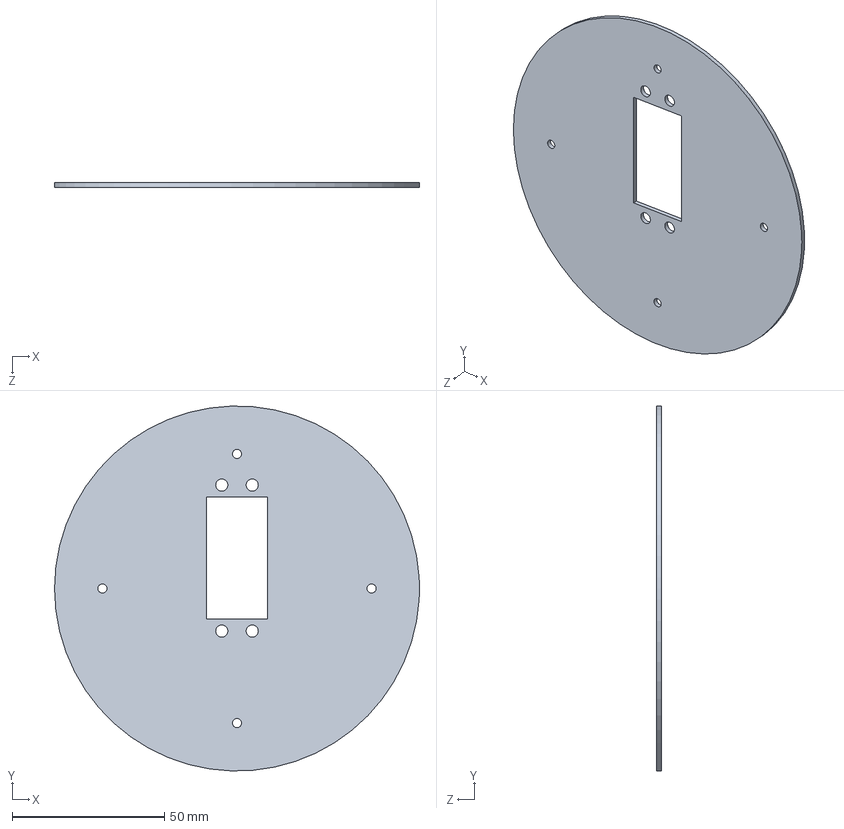
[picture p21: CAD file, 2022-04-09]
Machine/舵机云台支架.SLDPRT
120.0 x 119.9 x 1.50 mm

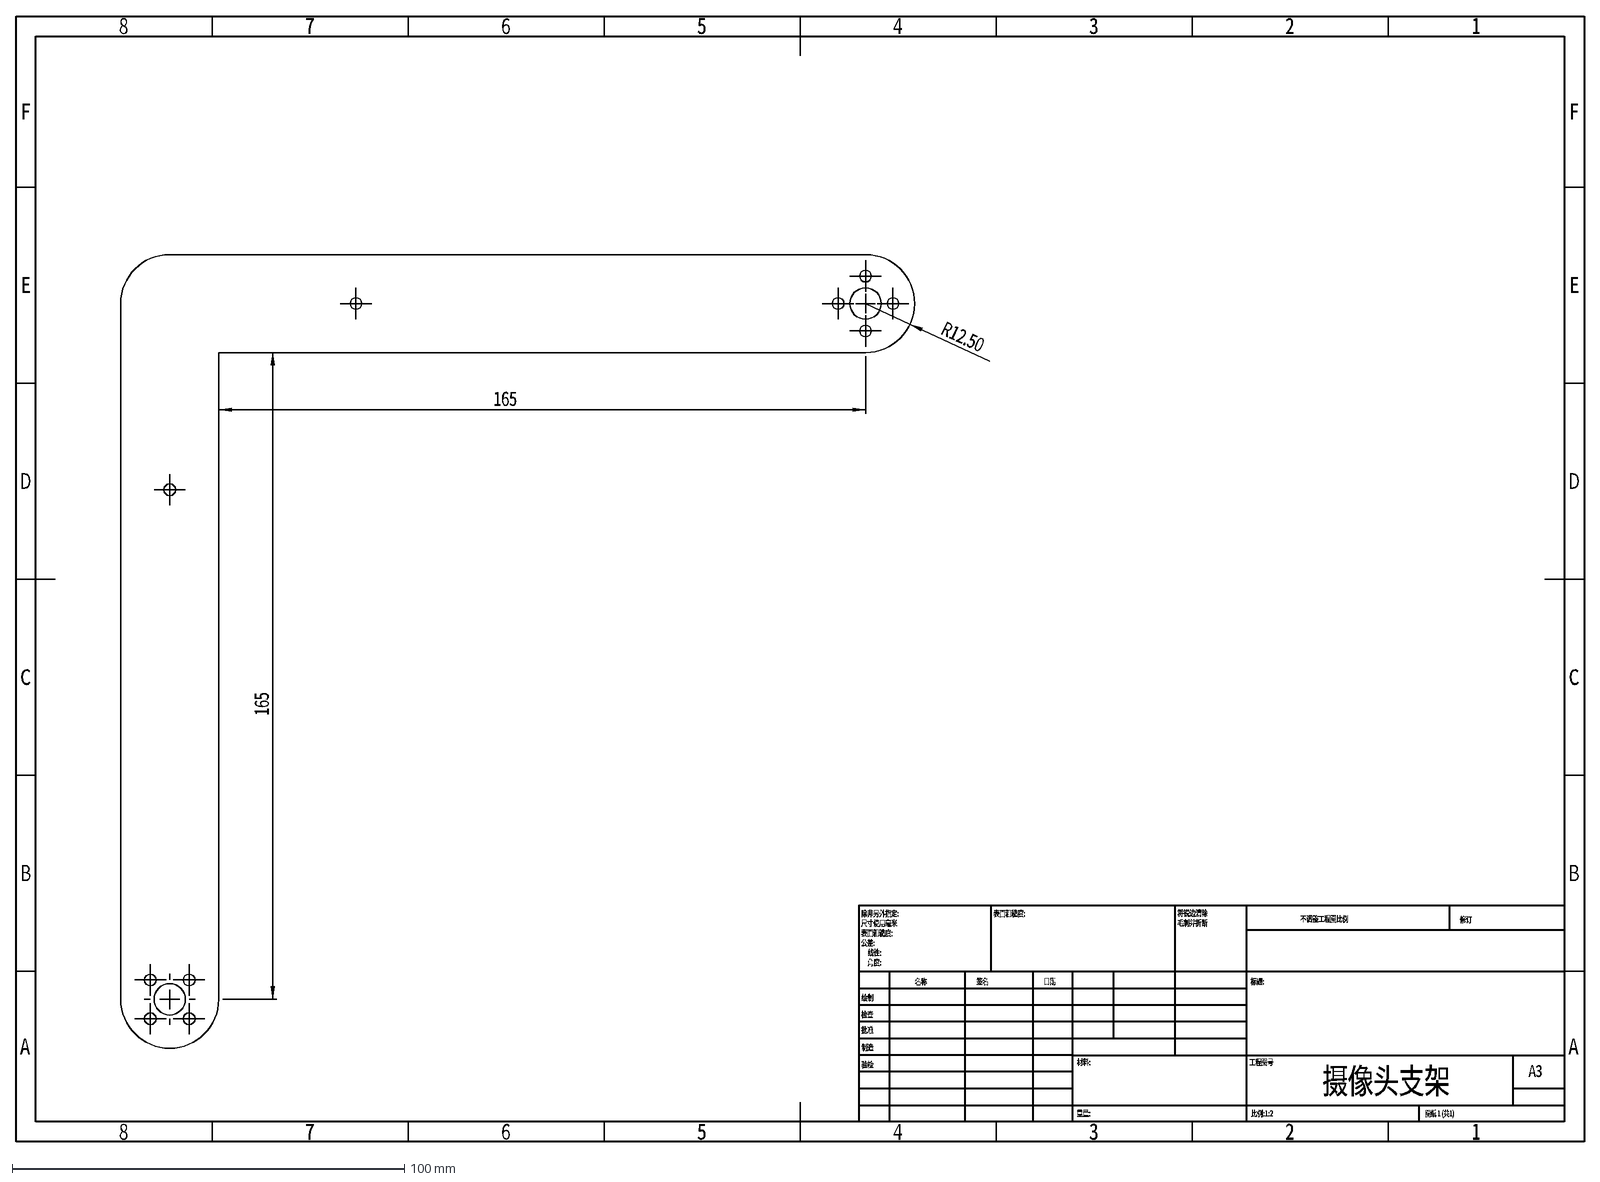
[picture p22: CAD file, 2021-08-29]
Machine/铝板切割DXF/摄像头支架.DXF
A
B
C
D
E
F
8
7
6
5
4
3
2
1
绘制
检查
批准
制造
验检
除非另外指定:
尺寸使用毫米
表面粗糙度:
公差:
线性:
角度:
将锐边清除
毛刺并折断
名称
签名
日期
材料:
不调整工程图比例
修订
标题:
工程图号
比例:1:2
图纸 1 (共1)
A3
重量:
摄像头支架
165
R12.50

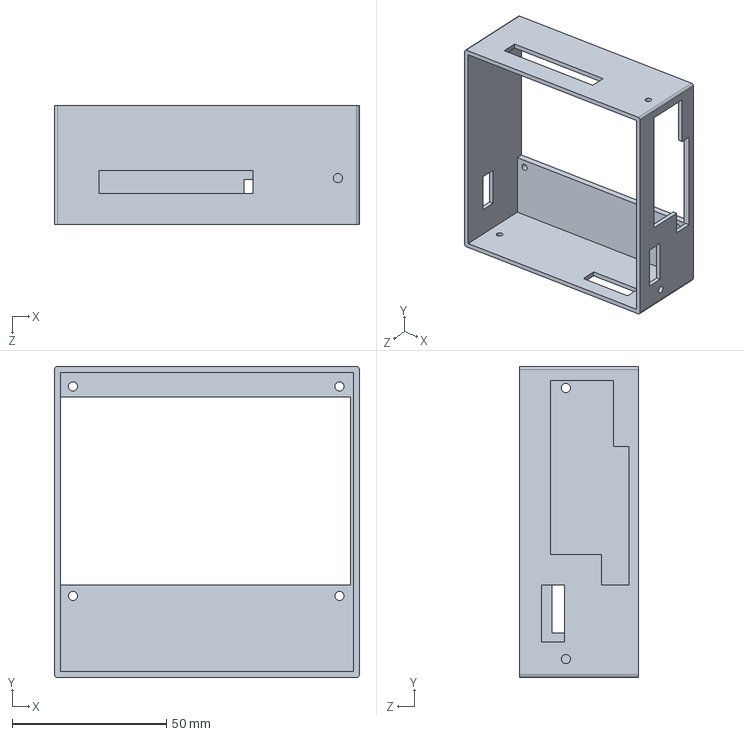
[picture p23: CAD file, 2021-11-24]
Machine/3D打印STL/图像处理模块外壳上壳.SLDPRT
99.0 x 101.0 x 38.5 mm

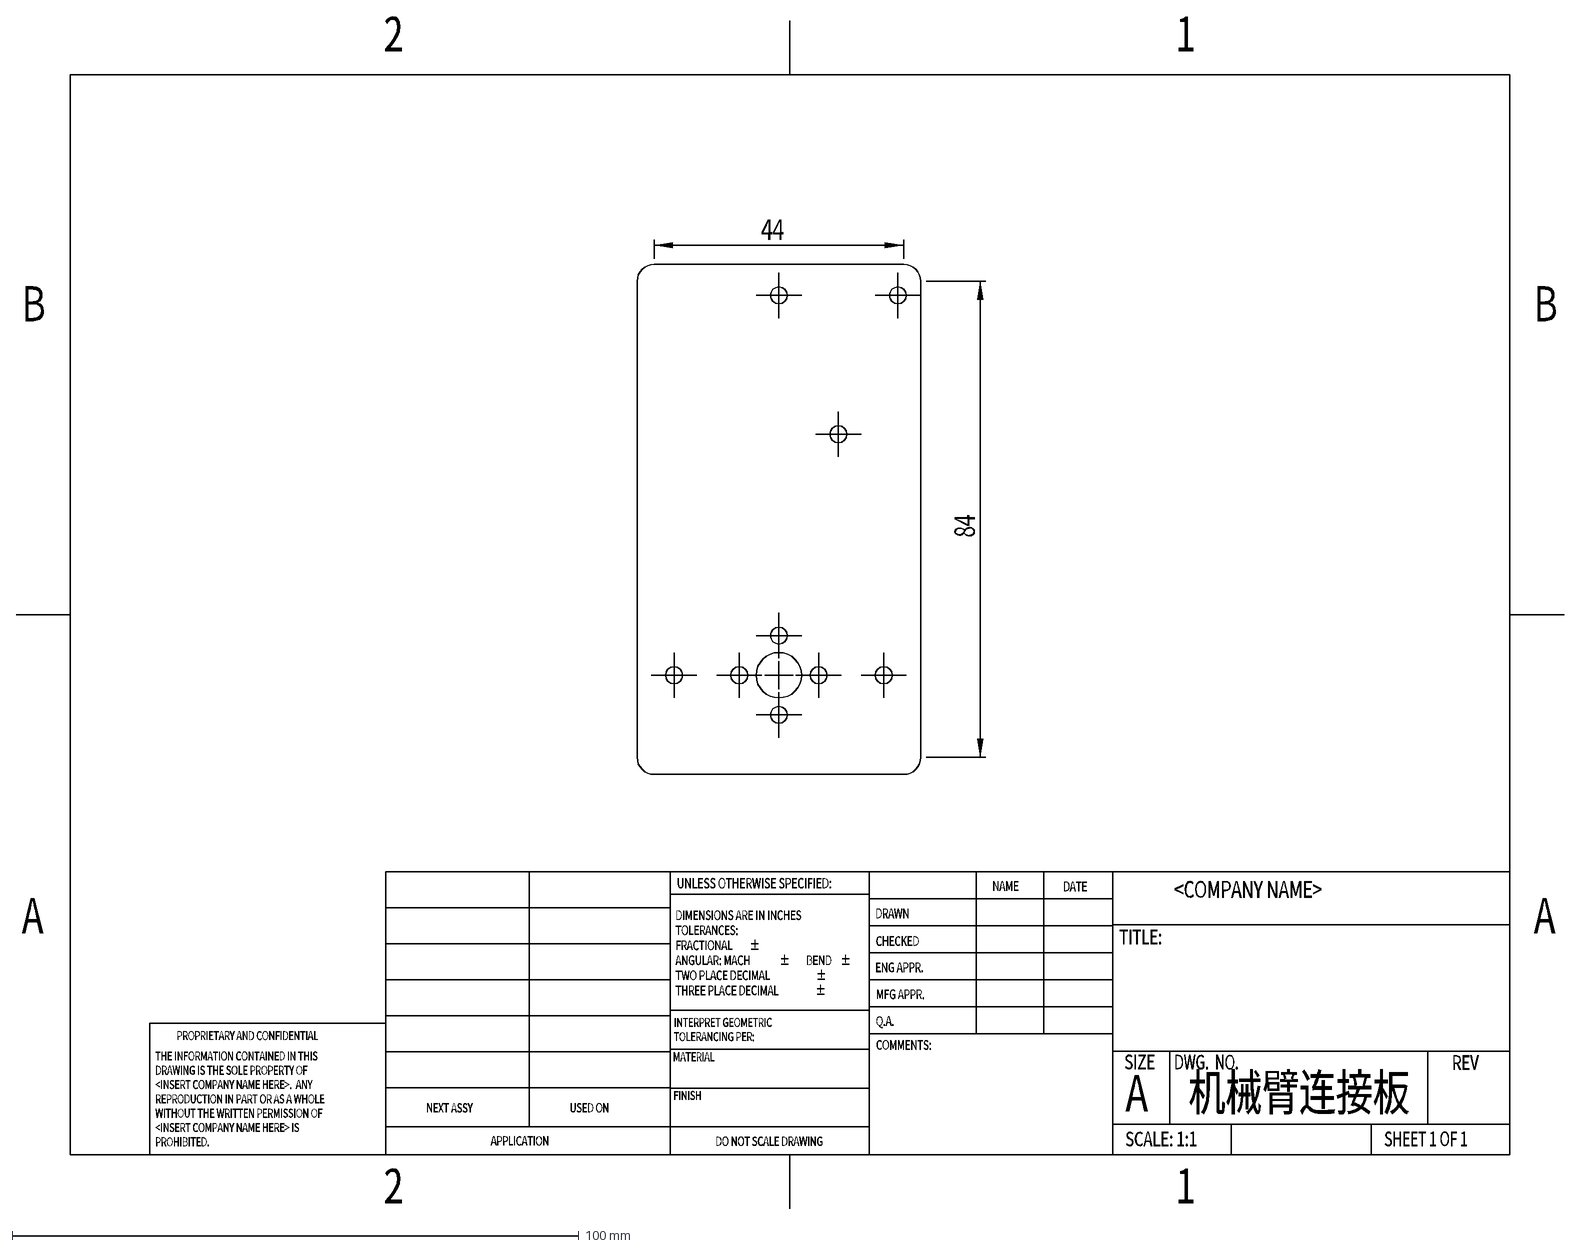
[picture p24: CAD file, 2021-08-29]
Machine/铝板切割DXF/机械臂连接板.DXF
UNLESS OTHERWISE SPECIFIED:
CHECKED
SIZE
APPLICATION
TITLE:
PROPRIETARY AND CONFIDENTIAL
INTERPRET GEOMETRIC
TOLERANCING PER:
Q.A.
FINISH
DWG. NO.
DATE
USED ON
A
DIMENSIONS ARE IN INCHES
TOLERANCES:
FRACTIONAL
±
ANGULAR: MACH
BEND
TWO PLACE DECIMAL
THREE PLACE DECIMAL
NEXT ASSY
MATERIAL
NAME
REV
DO NOT SCALE DRAWING
SCALE: 1:1
机械臂连接板
ENG APPR.
THE INFORMATION CONTAINED IN THIS
DRAWING IS THE SOLE PROPERTY OF
<INSERT COMPANY NAME HERE>. ANY
REPRODUCTION IN PART OR AS A WHOLE
WITHOUT THE WRITTEN PERMISSION OF
<INSERT COMPANY NAME HERE> IS
PROHIBITED.
COMMENTS:
DRAWN
MFG APPR.
SHEET 1 OF 1
2
1
B
<COMPANY NAME>
44
84

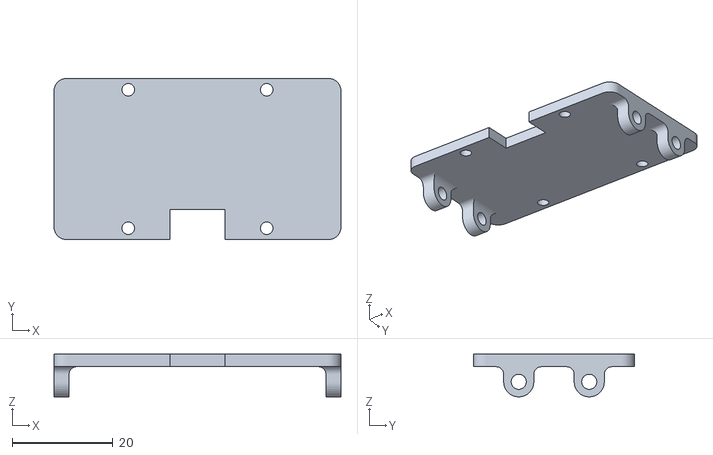
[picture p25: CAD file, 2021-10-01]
Machine/3D打印STL/摄像头支架.STL
57.0 x 32.0 x 8.49

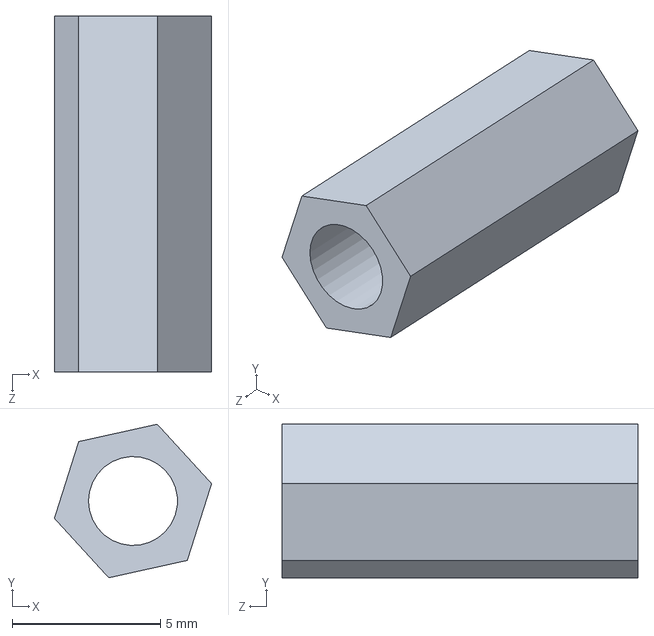
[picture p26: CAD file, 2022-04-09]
Machine/M3铜柱12mm.SLDPRT
5.30 x 5.17 x 12.0 mm

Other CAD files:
Machine/铝板切割dxf/机械臂杆件140mm.DXF
Machine/3D打印STL/磁铁竖向支架.STL
Machine/从动轮轴承.SLDPRT
Machine/铝板切割dxf/舵机云台中心圆盘转大圆盘底盘.DXF
Machine/16齿同步轮.SLDPRT
Machine/2020角件.SLDPRT
Machine/2040角件.SLDPRT
Machine/2040铝型材230mm.SLDPRT
Machine/2040铝型材300mm.SLDPRT
Machine/3429电机.SLDPRT
Machine/3D打印STL/TOFSuppter.STL
Machine/3D打印STL/丝杆底支架.STL
Machine/3D打印STL/丝杆滑台内支架.STL
Machine/3D打印STL/丝杆滑台外支架.STL
Machine/3D打印STL/丝杆滑块.STL
Machine/3D打印STL/丝杆螺母支架.STL
Machine/3D打印STL/丝杆顶支架.STL
Machine/3D打印STL/侧TOF支架.STL
Machine/3D打印STL/同步带轴承支架.STL
Machine/3D打印STL/图像处理模块外壳上壳.STL
Machine/3D打印STL/电池垫板.STL
Machine/3D打印STL/直线轴承支架.STL
Machine/3D打印STL/霍尔传感器支架.STL
Machine/42步进.SLDPRT
Machine/42步进35mm.SLDPRT
Machine/42步进40mm.SLDPRT
Machine/42步进支架.SLDPRT
Machine/5转8联轴器.SLDPRT
Machine/6mm滑杆220mm.SLDPRT
Machine/6mm滑杆307mm.SLDPRT
Machine/6mm滑杆直线轴承.SLDPRT
Machine/8mmx4丝杆285mm.SLDPRT
Machine/8mm丝杆轴承.SLDPRT
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

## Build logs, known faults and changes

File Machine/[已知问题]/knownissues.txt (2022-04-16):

机械的共振频率和舵机的共振频率相同, 导致机械臂极其抖动(但不影响使用)。
机械爪平抓控制精确但是不如吊抓精确。

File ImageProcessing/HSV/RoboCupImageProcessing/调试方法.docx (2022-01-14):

基础图像检测器(Detector)：

苹果、香蕉、猕猴桃、柠檬、橘子、桃子、香梨、火龙果、雪梨、靶标

分别对应英文：

Apple、Banana、KiwiFruit、Lemon、Orange、Peach、Pear、Pitaya、SnowPear、Target

以上所有基础图像检测器均继承自Detector类。该类图像检测实现方法为HSV颜色空间+形状判断。

本类基础公用配置参数有：

PositiveThresholds

NegativeThresholds

ReflectiveThresholds

MinimumSize

其中，

NegativeThresholds 的Value通道阈值尽量高

靶标调试：

由于桌子可能是红色的，所以需要先从白色区域内找红色。

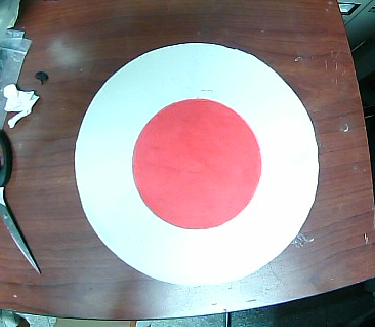
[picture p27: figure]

白色红色调试先后顺序无要求，白色为PositiveThresholds，红色为ReflectiveThresholds

随后调节圆形阈值。

1. 苹果：

易混种类：火龙果头部、猕猴桃、梨

参考配置：

FruitDetect

DetectorConfigs:

PositiveThresholds:

- [70, 110, 50, 255, 79, 255]

NegativeThresholds:

- [0, 65, 60, 255, 0, 255]

ReflectiveThresholds:

- [70, 255, 0, 255, 253, 255]

MinimumSize: 1300

ErodeKernelSize: 5

MinimunLengthWidthRatio: 0.65

PitayaThresholds:

- [210, 255, 175, 255, 125, 255]

MinimumPitayaSize: 1500

PositiveThresholds调试效果：

梨和苹果主要通过Hmin来区分

苹果Hmin略高于梨

当光线强度变弱，Hmin会上升（导致都认不出来），应下调Hmin

当光线强度增强，Hmin会下降（导致梨误识别为苹果），应上调Hmin

弱光下Hmin取70

正常光线取85

反光问题通过拉高Hmax来解决

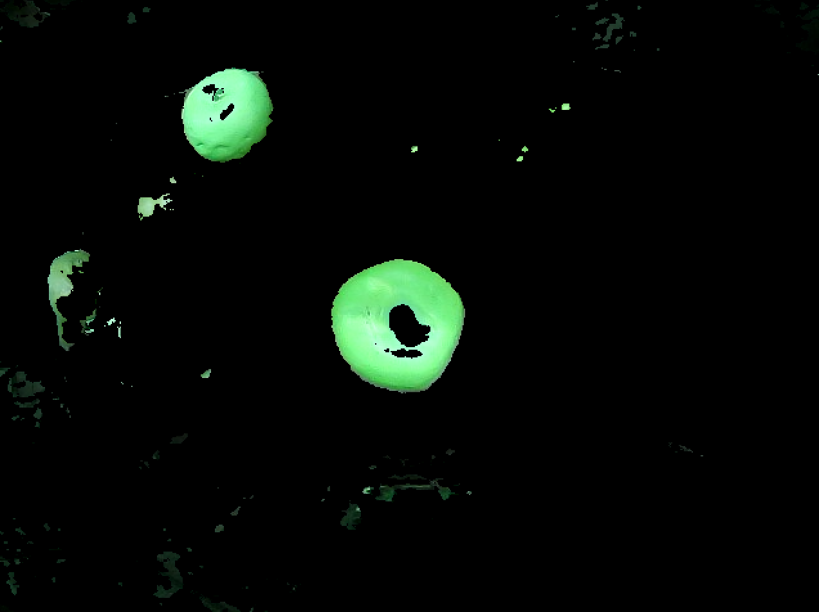
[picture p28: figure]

Hmin偏低：

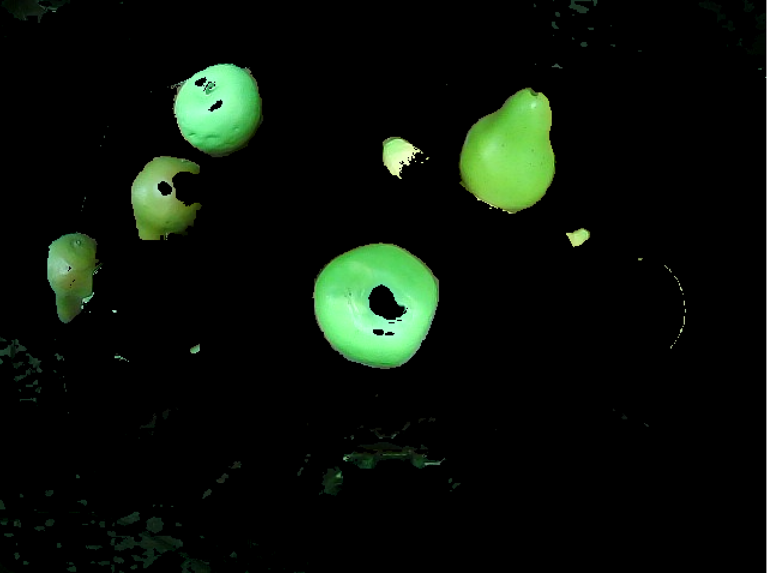
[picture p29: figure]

Hmin偏高

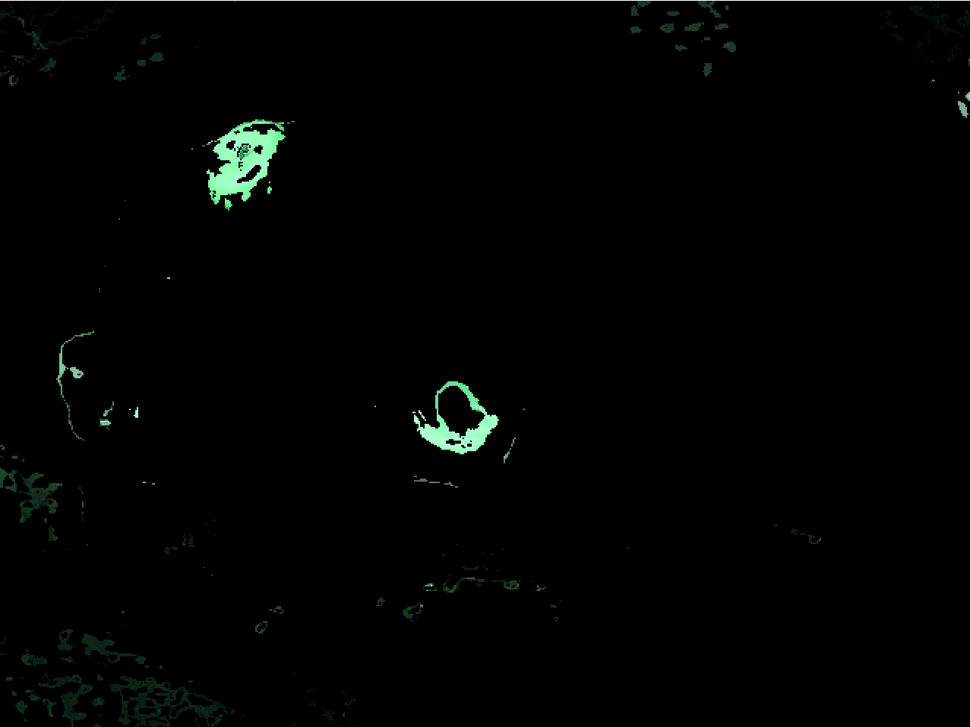
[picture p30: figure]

ReflectiveThresholds调试效果：

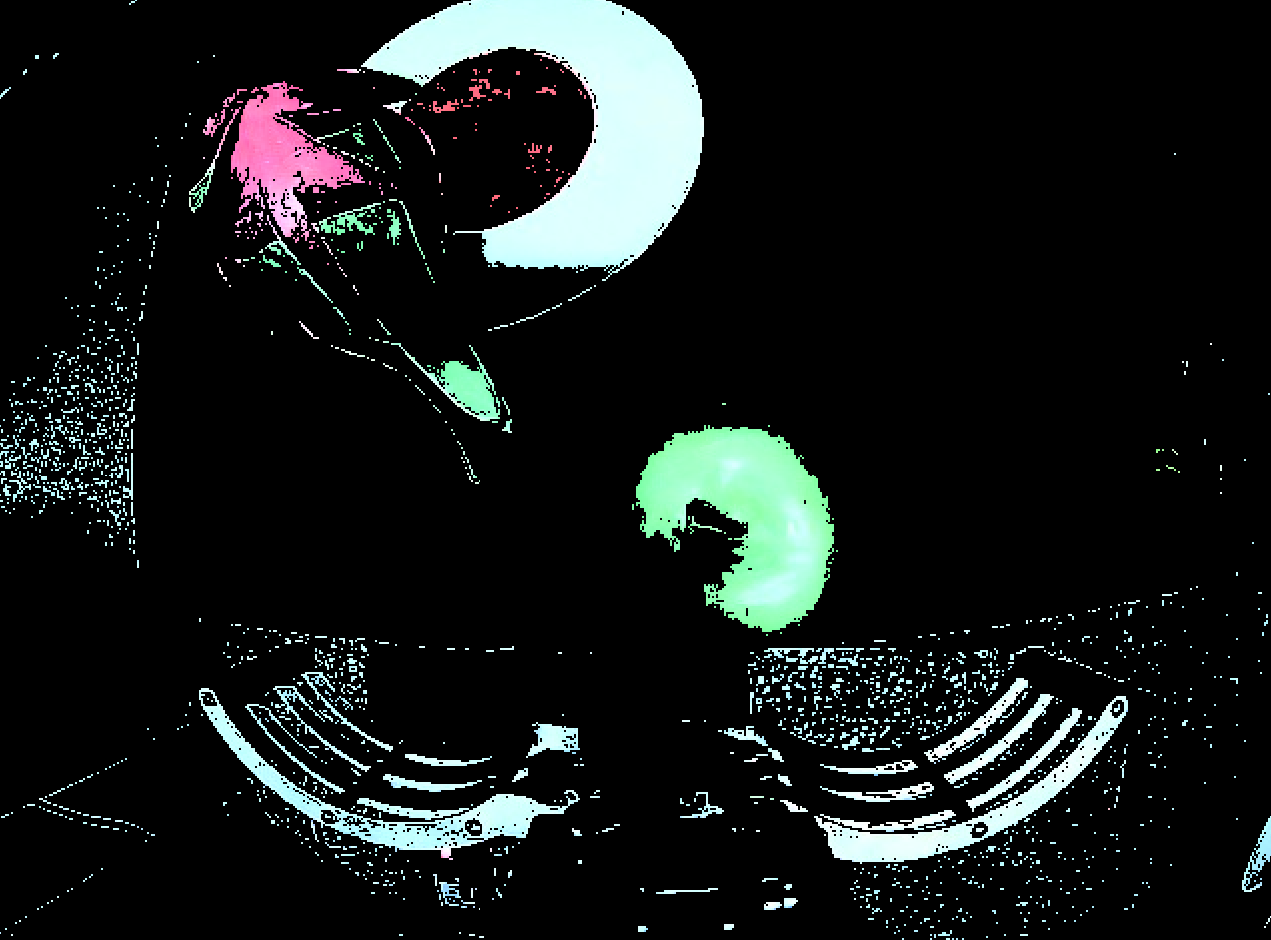
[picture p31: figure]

2. 柠檬

参考配置：

DetectorConfigs:

PositiveThresholds:

- [15, 36, 110, 255, 116, 255]

- [35, 50, 85, 220, 80, 255]

NegativeThresholds:

- [12, 24, 101, 255, 150, 255]

ReflectiveThresholds:

MinimumSize: 1300

ErodeKernelSize: 5

MinimunLengthWidthRatio: 0.55

5. 橘子(Orange)

只通过色调（Hmax Hmin）和饱和度（Smax Smin）来调节可能会和偏红色背景冲突，所以在偏红色背景下需要依靠明度(Vmax Vmin)来调节。

明度受光线影响较大

原图：

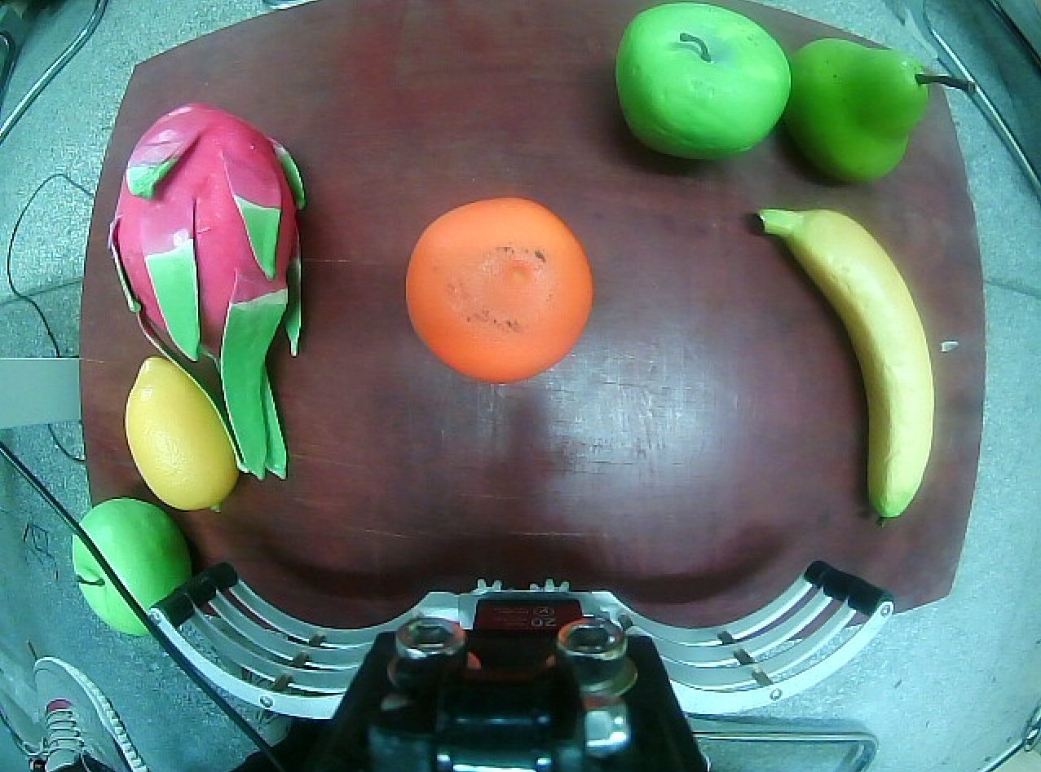
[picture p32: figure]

偏红色背景下，只依靠色相调节效果

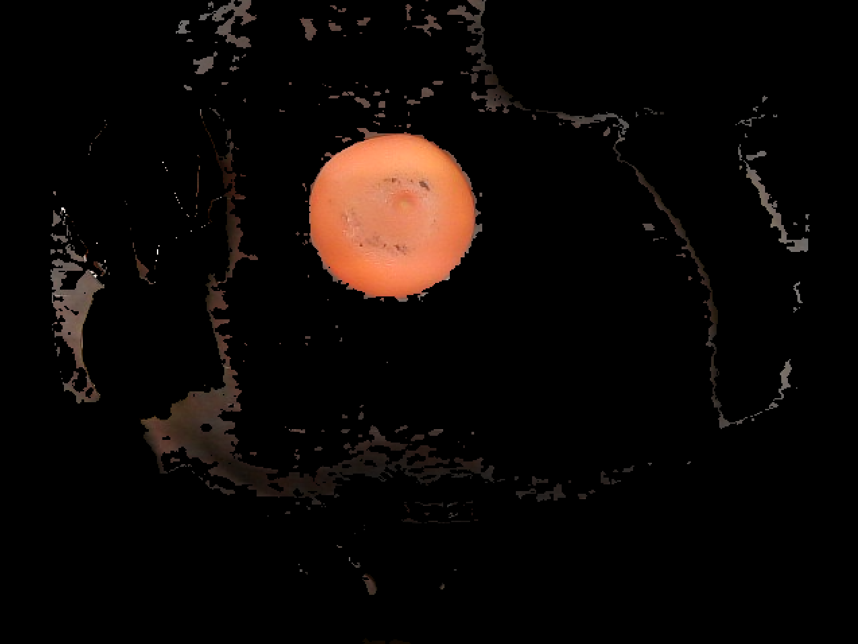
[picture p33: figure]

色相+饱和度：

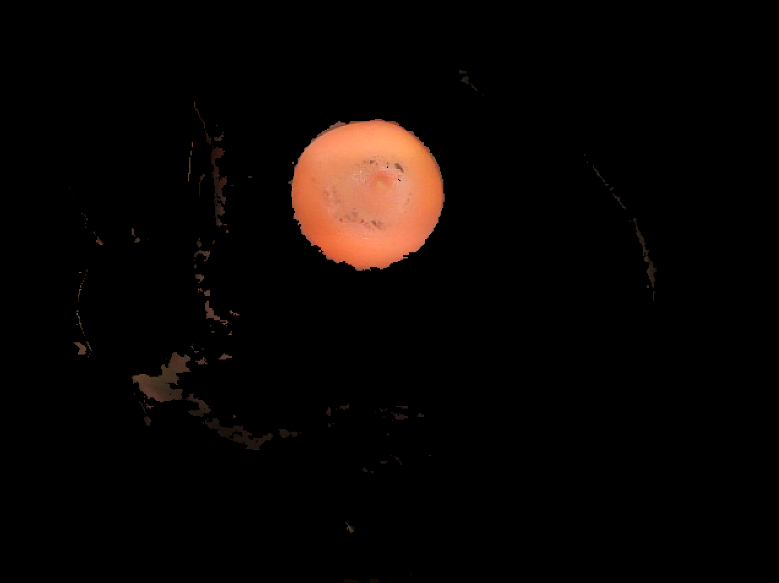
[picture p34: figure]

色相+饱和度+明度：

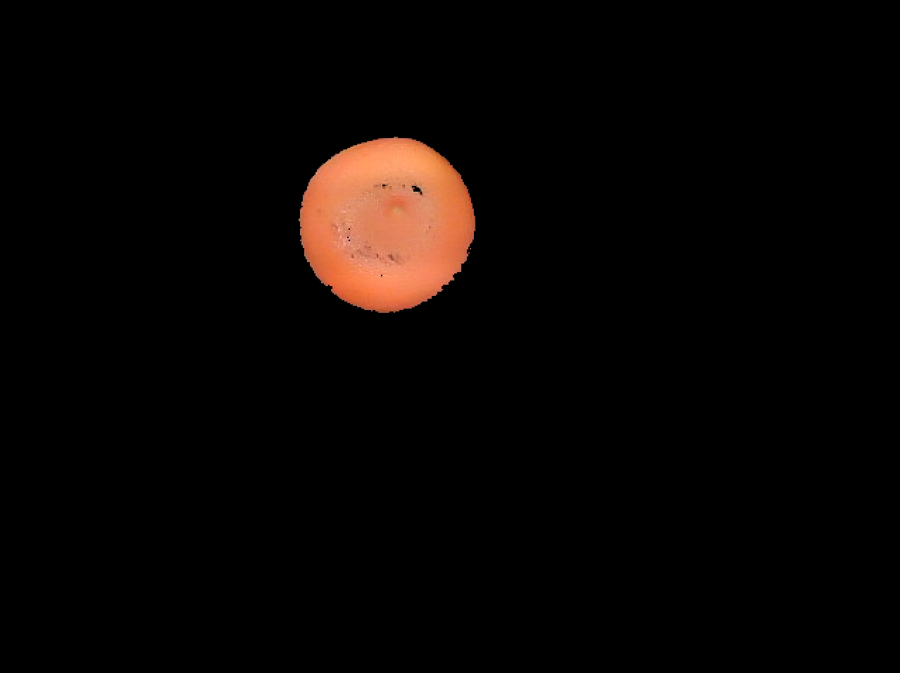
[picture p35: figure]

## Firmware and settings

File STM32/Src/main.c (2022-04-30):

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
/* Includes ------------------------------------------------------------------*/
#include "main.h"

/* USER CODE BEGIN Includes */
#include "App.h"
#include "RobotConfigs.h"
/* USER CODE END Includes */

I2C_HandleTypeDef hi2c1;

void SystemClock_Config(void);
static void MX_GPIO_Init(void);
static void MX_I2C1_Init(void);
static void MX_TIM1_Init(void);
static void MX_TIM2_Init(void);
static void MX_TIM3_Init(void);
static void MX_TIM7_Init(void);
static void MX_UART4_Init(void);
static void MX_UART5_Init(void);
static void MX_USART1_UART_Init(void);
static void MX_USART3_UART_Init(void);
static void MX_SPI1_Init(void);
static void MX_TIM8_Init(void);
static void MX_TIM6_Init(void);
static void MX_TIM5_Init(void);
static void MX_TIM4_Init(void);
/**
  * @brief  The application entry point.
  * @retval int
  */
int main(void)
{
  /* MCU Configuration--------------------------------------------------------*/

  /* Reset of all peripherals, Initializes the Flash interface and the Systick. */
  HAL_Init();

  /* Configure the system clock */
  SystemClock_Config();

  /* Initialize all configured peripherals */
  MX_GPIO_Init();
  MX_I2C1_Init();
  MX_TIM1_Init();
  MX_TIM2_Init();
  MX_TIM3_Init();
  MX_TIM7_Init();
  MX_UART4_Init();
  MX_UART5_Init();
  MX_USART1_UART_Init();
  MX_USART3_UART_Init();
  MX_SPI1_Init();
  MX_TIM8_Init();
  MX_TIM6_Init();
  MX_TIM5_Init();
  MX_TIM4_Init();
  /* USER CODE BEGIN 2 */

  //Run Application
  App();

  /* USER CODE END 2 */

  /* Infinite loop */
  /* USER CODE BEGIN WHILE */
  while (1)
  {
    /* USER CODE END WHILE */

    /* USER CODE BEGIN 3 */
  }
  /* USER CODE END 3 */
}

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


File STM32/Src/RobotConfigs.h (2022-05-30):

/*
 * RobotConfigs.h
 *
 *  Created on: 2021Äê8ÔÂ9ÈÕ
 *      Author: h13
 */

#ifndef ROBOTCONFIGS_H_
#define ROBOTCONFIGS_H_

/**
 * @group: App Configs.
 */
/***********************Motion Control**********************/
/**
 * @group: Motion control configs.
 * @param:
 * 		angleAccuracy:   Angle accuracy limit in angle.
 * 		forwardAccuracy: Forward accuracy limit in millimeter.
 * 		stableTimeLimit: Stable Time Limit in milliseconds.
 */
#define MaxSpeed                                     (2500)  //
//DeadZone
#define ForwardDeadZone                              (0.0)
#define BackwardDeadZone                             (0.0)
//Accurary
#define AngleAccurary                                (2.0)   //degree
#define AngleAdjustTimeLimit                         (6000)  //milliseconds
#define AngleStableTimeThreshold                     (500)   //milliseconds
#define ForwardAccuracy                              (20)    //millimeters
#define ForwardAdjustTimeLimit                       (15000)
#define ForwardStableTimeThreshold                   (500)
#define ForwardTrimDistance                          (50)    //millimeters, under this distance error, the angle loop is closed to improve the approximation speed.
#define ForwardTrimAngleErrorLimit                   (2.0)   //degree, allowable angle error when fine tuning distance.
#define ForwardTrimTimeLimit                         (3000)  //milliseconds
//Motion parameters.
#define DisktopDistanceBeforeTurn                    (560)   //millimeters

//PID
//Speed PID
#define SpeedPID_Proportion                          (0.002500)
#define SpeedPID_Integration                         (0.000080)
#define SpeedPID_Differention                        (0.000075)
//Angle PID
#define AnglePID_Proportion                          (500.0)
#define AnglePID_Integration                         (0.0)
#define AnglePID_Differention                        (20.0)
//Forward PID
#define ForwardPID_Proportion                        (-5.0)
#define ForwardPID_Integration                       (0.0)
#define ForwardPID_Differention                      (0.0)

/************************Arm Control************************/
//Arm control parameters.
#define GrabHeight                                   (275)                                               //millimeters
#define ApproachHeight                               (GrabHeight + 25 > 305 ? 305 : GrabHeight + 25)     //millimeters
//#define RetractionHeight                             (ApproachHeight + 50)                             //millimeters
#define BaseAxialLength                              (210)                                               //millimeters
#define CatchAppleElongationDistance                 (0)                                                 //millimeters
#define PlaceAppleElongationDistance                 (180)//150                                          //millimeters
#define WashAppleHeight                              (350)                                               //millimeters
#define WashAppleAxialLength                         (245)                                               //millimeters
#define ThrowAppleAxialLength                        (0)
#define ThrowAppleHeight                             (0)

//Grub center configs.
#define AppleAimCenterX                              (1 - 0.472)
#define AppleAimCenterY                              (0.60)
#define TargetAimCenterX                             (1 - 0.472 - 0.020)
#define TargetAimCenterY                             (0.18)
#define FruitAimCenterX                              (0.5)
#define FruitAimCenterY                              (0.35)

//Grub tolerance error configs.
#define AppleToleranceErrorX                         (0.025)
#define AppleToleranceErrorY                         (0.025)
#define TargetToleranceErrorX                        (0.0125)
#define TargetToleranceErrorY                        (0.0125)
#define FruitIdentifyToleranceErrorX                 (0.035)
#define FruitIdentifyToleranceErrorY                 (0.035)
#define ClawStableTimesLimit                         (200)                                               //microseconds

//PID configs
#define X_AxisPID_Proportion                         (-2.0)
#define X_AxisPID_Integration                        (0.0)

#define Y_AxisPID_Proportion                         (7.80)
#define Y_AxisPID_Integration                        (0.005)

/*************************Arm Config************************/
//List of available arm types.
#define MechanicalArm                                0
#define LiftingPlatform                              1

//Arm type selection.
#define ArmType                                      LiftingPlatform
#define MaximumRotationAngleOfGraspingApple          (90)
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

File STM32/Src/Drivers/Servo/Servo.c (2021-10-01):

/*
 * Servo.c
 *
 *  Created on: 2021Äê6ÔÂ4ÈÕ
 *      Author: h13
 */
#include "Servo.h"
#include "RobotConfigs.h"
#include "PWM.h"

typedef struct
{
	PWM_t PWM;
	const float MaximumRotationAngle;
	const float RotationProportion;
	const float RotationOffset;
	float CurrentAngle;
} Servo_t;

static Servo_t armRotationServo    = { .PWM = (PWM_t)ArmRotationServo,   .MaximumRotationAngle = ArmRotationServoMaximumRotationAngle,   .RotationProportion = ArmRotationServoProportion,   .RotationOffset = ArmRotationServoOffset,   .CurrentAngle = 0.0 };
static Servo_t armElongationServo  = { .PWM = (PWM_t)ArmElongationServo, .MaximumRotationAngle = ArmElongationServoMaximumRotationAngle, .RotationProportion = ArmElongationServoProportion, .RotationOffset = ArmElongationServoOffset, .CurrentAngle = 0.0 };
static Servo_t armParallelServo    = { .PWM = (PWM_t)ArmParallelServo,   .MaximumRotationAngle = ArmParallelServoMaximumRotationAngle,   .RotationProportion = ArmParallelServoProportion,   .RotationOffset = ArmParallelServoOffset,   .CurrentAngle = 0.0 };
static Servo_t clawRotationServo   = { .PWM = (PWM_t)ClawRotationServo,  .MaximumRotationAngle = 180,                                    .RotationProportion = 1.0,                          .RotationOffset = ClawRotationServoOffset,  .CurrentAngle = 0.0 };
static Servo_t clawGrabServo       = { .PWM = (PWM_t)ClawGrabServo,      .MaximumRotationAngle = 180,                                    .RotationProportion = 1.0,                          .RotationOffset = 0.0,                      .CurrentAngle = 0.0 };

#if(ArmType == MechanicalArm)
static float node3_Angle = 0;
static Servo_t armElongationServo2 = { .PWM = (PWM_t)ArmElongationServo2, .MaximumRotationAngle = ArmElongationServo2_MaximumRotationAngle, .MinimumRotationAngle = ArmElongationServo2_MinimumRotationAngle, .RotationProportion = ArmElongationServo2_Proportion, .MinimumRotationAngle = ArmElongationServo2_Offset };
#endif

void ServoInit(void)
{
#if(ArmType == MechanicalArm)
	PWM_Init(&armRotationServo.PWM);
	PWM_Init(&armElongationServo.PWM);
	PWM_Init(&armElongationServo2.PWM);
	PWM_Init(&armParallelServo.PWM);
	PWM_Init(&clawRotationServo.PWM);
	PWM_Init(&clawGrabServo.PWM);
#elif(ArmType == LiftingPlatform)
	PWM_Init(&armRotationServo.PWM);
	PWM_Init(&armElongationServo.PWM);
	PWM_Init(&armParallelServo.PWM);
	PWM_Init(&clawRotationServo.PWM);
	PWM_Init(&clawGrabServo.PWM);
#endif
}


/**
 * @brief: Control servos movement to the calibration point to facilitate mechanical calibration.
 */
void CalibrationAllServo(void)
{
#if(ArmType == MechanicalArm)
	SetArmNodeAngle(ArmRotation, 0);
	SetArmNodeAngle(ArmElongationNode0, 0);
	SetArmNodeAngle(ArmElongationNode1, 0);
	SetArmNodeAngle(ArmParallel, 0);
	SetArmNodeAngle(ClawRotation, 0);
	SetArmNodeAngle(ClawGrab, 0);
#elif(ArmType == LiftingPlatform)
	SetArmNodeAngle(ArmRotation, 0);
	SetArmNodeAngle(ArmElongation, 0);
	SetArmNodeAngle(ArmParallel, 0);
	SetArmNodeAngle(ClawRotation, 0);
	SetArmNodeAngle(ClawGrab, 180);
#endif
}

/**
 * @brief: Set servo angle.
 * @param: Angle.
 * @note:  Clockwise is positive.
 */
__attribute__((always_inline)) inline static void setServoAngle(Servo_t *Servo, float Angle)
{
	//FinalAngle = ((Angle + Servo -> RotationOffset) * Servo -> RotationProportion)
	//HighLevelTime = (FinalAngle / Servo -> MaximumRotationAngle) * 2000.0 + 500.0
	float highLevelTime = 2500 - (((Angle + Servo -> RotationOffset) * Servo -> RotationProportion) / Servo -> MaximumRotationAngle) * 2000.0;

	if(highLevelTime > 2500.0)
	{
		highLevelTime = 2500.0;
		Servo -> CurrentAngle = Servo -> MaximumRotationAngle;
	} else if(highLevelTime < 500.0)
	{
		highLevelTime = 500.0;
		Servo -> CurrentAngle = 0.0;
	} else {
		Servo -> CurrentAngle = Angle;
	}
	SetPWM_HighLevelTime(&(Servo -> PWM), highLevelTime);
}

/**
 * @brief: Set the rotation angle of the Arm node.
 * @param:
 * 		ArmNode_t Node: The arm node to be set.
 * 		float Angle:    Angle to rotate.
 */
void SetArmNodeAngle(ArmNode_t Node, float Angle)
{
	switch(Node)
	{
	case ArmRotation:
		setServoAngle(&armRotationServo, Angle);
		break;

	case ArmElongation:
		setServoAngle(&armElongationServo, Angle);
		break;

	case ArmParallel:
		setServoAngle(&armParallelServo, Angle);
		break;

#if(ArmType == MechanicalArm)
	case ArmElongationNode0:
		setServoAngle(&armElongationServo2, Angle);
		break;
#endif

	case ClawRotation:
		setServoAngle(&clawRotationServo, Angle);
		break;

	case ClawGrab:
		setServoAngle(&clawGrabServo, Angle);
		break;

	default:
		break;
	}
}

/**
 * @brief: Smooth rotation arm node.
 * @param:
 * 		ArmNode_t Node:                The arm node to be set.
 * 		float Angle:                   Angle to rotate.
 * 		mtime_t MillisecondsPerDegree: Milliseconds per degree.
 */
void SmoothRotateArmNode(ArmNode_t Node, float Angle, mtime_t MillisecondsPerDegree)
{
	Servo_t *servo = NULL;
	switch(Node)
	{
	case ArmRotation:
		servo = &armRotationServo;
		break;

	case ArmElongation:
		servo = &armElongationServo;
		break;

	case ArmParallel:
		servo = &armParallelServo;
		break;

	case ClawRotation:
		servo = &clawRotationServo;
		break;

	case ClawGrab:
		servo = &clawGrabServo;

	default:
		return;
	}

	while(Angle != servo -> CurrentAngle)
	{
		if(Angle > servo -> CurrentAngle)
		{
			servo -> CurrentAngle += 1.0;
		} else if(Angle < servo -> CurrentAngle)
		{
			servo -> CurrentAngle -= 1.0;
		}

		setServoAngle(servo, servo -> CurrentAngle --);

		SleepMillisecond(MillisecondsPerDegree);
	}
}

/**
 * @brief:  Get the rotation angle of the Arm node.
 * @param:
 * 		ArmNode_t Node: The arm node to get.
 * @return: Current angle.
 */
float GetArmNodeAngle(ArmNode_t Node)
{
	switch(Node)
	{
	case ArmRotation:
		return armRotationServo.CurrentAngle;
		break;

	case ArmElongation:
		return armElongationServo.CurrentAngle;
		break;

	case ArmParallel:
		return armParallelServo.CurrentAngle;
		break;

	case ClawRotation:
		return clawRotationServo.CurrentAngle;
		break;

	case ClawGrab:
		return clawGrabServo.CurrentAngle;
		break;

	default:
		return 0;
		break;
	}
}

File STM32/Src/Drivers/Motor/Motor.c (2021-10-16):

/*
 * Motor.c
 *
 *  Created on: 2021Äê6ÔÂ3ÈÕ
 *      Author: h13
 */
#include "Motor.h"
#include "RobotConfigs.h"
#include <assert.h>
#include "Ports.h"

#define PositiveZero (0.001)
#define NegativeZero (-0.001)

#if(!ReverseLeftRight)

#if(!ReverseChannel1)
static PWM_t channelD0 = PWM_ChannelD0;
static PWM_t channelD1 = PWM_ChannelD1;
#else
static PWM_t channelD0 = PWM_ChannelD1;
static PWM_t channelD1 = PWM_ChannelD0;
#endif

#if(!ReverseChannel2)
static PWM_t channelD2 = PWM_ChannelD2;
static PWM_t channelD3 = PWM_ChannelD3;
#else
static PWM_t channelD2 = PWM_ChannelD3;
static PWM_t channelD3 = PWM_ChannelD2;
#endif

#else

#if(!ReverseChannel1)
static PWM_t channelD0 = PWM_ChannelD2;
static PWM_t channelD1 = PWM_ChannelD3;
#else
static PWM_t channelD0 = PWM_ChannelD3;
static PWM_t channelD1 = PWM_ChannelD2;
#endif

#if(!ReverseChannel2)
static PWM_t channelD2 = PWM_ChannelD0;
static PWM_t channelD3 = PWM_ChannelD1;
#else
static PWM_t channelD2 = PWM_ChannelD1;
static PWM_t channelD3 = PWM_ChannelD0;
#endif

#endif

/**
 * @brief: Initialize the H-bridge module and PWM peripherals.
 */
void MotorInit()
{
	assert((channelD0.Frequency == channelD1.Frequency) && (channelD2.Frequency == channelD3.Frequency));
	assert((channelD0.ReloadValue == channelD1.ReloadValue) && (channelD2.ReloadValue == channelD3.ReloadValue));

	PWM_Init(&channelD0);
	PWM_Init(&channelD1);
	PWM_Init(&channelD2);
	PWM_Init(&channelD3);
}

/**
 * @brief:  Get the max value of pwm.
 * @return: 1.0 - deadZone.
 */
__attribute__((always_inline)) inline float GetMaxValueOfPWM(void)
{
	return 1.0 - ForwardDeadZone;
}

/**
 * @brief: Set the left motor PWM.
 * @param: PWM Value, Range: [-1.0, 1.0]
 */
void SetLeftMotorPWM(float PWM_DutyRatio)
{
	if(PWM_DutyRatio > PositiveZero)
	{
		PWM_DutyRatio += ForwardDeadZone;
		if(PWM_DutyRatio < 1.0)
		{
			SetPWM_DutyRatio(&channelD0, PWM_DutyRatio);
			SetPWM_DutyRatio(&channelD1, 0);
		} else {
			SetPWM_DutyRatio(&channelD0, 1);
			SetPWM_DutyRatio(&channelD1, 0);
		}
	} else if(PWM_DutyRatio < NegativeZero)
	{
		PWM_DutyRatio = - PWM_DutyRatio + BackwardDeadZone;
		if(PWM_DutyRatio > - 1.0)
		{
			SetPWM_DutyRatio(&channelD0, 0);
			SetPWM_DutyRatio(&channelD1, PWM_DutyRatio);
		} else {
			SetPWM_DutyRatio(&channelD0, 0);
			SetPWM_DutyRatio(&channelD1, 1);
		}
	} else {
		SetPWM_DutyRatio(&channelD0, 0);
		SetPWM_DutyRatio(&channelD1, 0);
	}
}

/**
 * @brief: Set the Right motor PWM.
 * @param: PWM Value, Range: [-1.0, 1.0]
 */
void SetRightMotorPWM(float PWM_DutyRatio)
{
	if(PWM_DutyRatio > PositiveZero)
	{
		PWM_DutyRatio += ForwardDeadZone;
		if(PWM_DutyRatio < 1.0)
		{
			SetPWM_DutyRatio(&channelD2, PWM_DutyRatio);
			SetPWM_DutyRatio(&channelD3, 0);
		} else {
			SetPWM_DutyRatio(&channelD2, 1);
			SetPWM_DutyRatio(&channelD3, 0);
		}
	} else if(PWM_DutyRatio < NegativeZero)
	{
		PWM_DutyRatio = - PWM_DutyRatio + BackwardDeadZone;
		if(PWM_DutyRatio > - 1.0)
		{
			SetPWM_DutyRatio(&channelD2, 0);
			SetPWM_DutyRatio(&channelD3, PWM_DutyRatio);
		} else {
			SetPWM_DutyRatio(&channelD2, 0);
			SetPWM_DutyRatio(&channelD3, 1);
		}
	} else {
		SetPWM_DutyRatio(&channelD2, 0);
		SetPWM_DutyRatio(&channelD3, 0);
	}
}

/**
 * @brief: Brake(Apply electromagnetic damped brakes)
 */
void Brake(void)
{
	SetPWM_DutyRatio(&channelD0, 1);
	SetPWM_DutyRatio(&channelD1, 1);
	SetPWM_DutyRatio(&channelD2, 1);
	SetPWM_DutyRatio(&channelD3, 1);
}

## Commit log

2021-06-14 第一次提交。
    已完成功能：
    0. 代码重构方便更换为标准库或Hal库
    1. 完成MPU9250驱动
    2. 完成SK-Z TOF驱动
    3. 完成SSD1283屏幕驱动
    4. 完成LVGL移植
    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
    [TOFSuppter.SLDPRT, TOFSuppter.STL]
2021-06-21 优化部分api
    更新：
    Log支持可变参数
    重构PID.c
    逐步将位操作替换为位域
    添加VL53L0X驱动
    加入VL53L0X辅助SK-Z-10-TOF
    [TOFSuppter.SLDPRT, TOFSuppter.STL]
2021-06-21 修复BUG
    修复位置式PID中的部分bug
    规范部分函数拼写
    TODO：优化代码结构，优化PID参数
2021-06-21 删除无用文件
2021-06-22 更新部分软硬件设计，修复部分BUG
    更新：将MPU9250替换为EPSON XV7011（WT101）
    更新：支持选择地板粗糙度
    更新：支持前进命令
    更新：优化PID参数获取方式
    更新：修复PID中部分拼写错误
    更新：删除不再需要的MPU9250，VL53L0X驱动
    修复：SK-TOF驱动数据读取BUG
    修复：H桥驱动BUG
    TODO：将WT101更换为I2C模式或者替换为普通XV7011模块
    [Motor.c, STM32.ioc, WT101.c]
2021-06-22 重构项目结构
    重构：将debug api从platform移动到app文件夹下
2021-06-23 更新：优化部分API，修复部分BUG
    更新：MotionControl支持跨越跳跃点（±180°）控制
    更新：WT101支持选择偏航角极性
    更新：导出VOFA上位机配置
    更新：PID支持自定义误差和自定义误差速率
    [WT101.c]
2021-06-23 优化运动控制
    更新：将角度环所使用的"PosPID_CalcWithCustErr"更换为"PosPID_CalcWithCustErrAndDiff"
    + fix #3
    [WT101.c]
2021-06-23 优化代码结构，清除无用API
    重构项目，将中断移动到Platform文件夹下
    + fix #2
    [TimerInterrupts.c]
2021-06-26 更新：优化部分API，修复部分BUG
    更新：将项目中全部HAL库实现替换为LL
    更新：用LL库实现微秒级时间控制
    更新：优化SPI超时宏
    修复：转向时低概率触发的bug
    修复：转向最优方向BUG
    优化：KeepAngle和KeepDistance API声明
    优化：删除无用代码
    + fix #4
    + fix #5
    + fix #6
    + fix #7
    [I2C.c, SPI.c, SSD1283.c]
2021-08-09 修复Bug，添加功能
    更新：支持OpenMV的Cascade级联分类器进苹果的目标检测
    更新：添加4430张数据集，支持使用K210 yoloV2进行 `苹果` `香蕉` `猕猴桃` `柠檬` `火龙果`等目标的识别
    更新：支持使用几何方式控制机械臂运动
    更新：删除位操作库，使用`SimpleProtocolPraise`进行协议解析
    更新：更新`FastMatch`库
    更新：校准了舵机
    更新：添加K210的摄像头支架
    TODO：
    0. 完善`RobotConfig.h`并使用menuconfig进行配置
    1. 将`ArmControlConfigs.h`并入`RobotConfig.h`
    2. 提供舵机校准参数对应接口
    3. 完善Example下各种功能测试程序
    [CameraSupport70VersionPart1.SLDPRT, CameraSupport70VersionPart1.STL, K210Supporter.SLDPRT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]
2021-08-10 修复部分问题
    更新：统一部分API写法
    修复：机械臂在几何控制时可能触发的bug
    [丝杆滑块.SLDPRT, 旋转云台旋转盘.SLDPRT, 铝型材.SLDPRT]
2021-08-10 优化文件结构 移植部分驱动 完善部分文档
    更新：适配VL6180X驱动
    更新：完成部分机械臂闭环驱动代码编写
    更新：添加图像处理部分文档
    更新：将I2C切换回HAL库
    + fix #1
    [I2C.c, RobotConfigs.h, STM32.ioc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]
2021-08-11 修复bug 修复文档 优化API
    修复：修复机械臂失控的bug
    修复：文档拼写错误
    [RobotConfigs.h]
2021-08-14 更新机械结构设计 支持机械臂抓取苹果
    更新：开启第二版机械臂设计
    更新：第一版机械臂支持抓取苹果
    更新：优化工程结构
    更新：优化机械臂控制方式
    [2020角件.SLDPRT, 2040角件.SLDPRT, 2040铝型材230mm.SLDPRT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]
2021-08-15 更新机械结构设计
    [16齿同步轮.SLDPRT, 42步进35mm.SLDPRT, 42步进支架.SLDPRT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]
2021-08-23 增加部分API 增加更多功能 修复已知问题
    1. 增加图像处理部分任务调度和通信协议实现
    2. 更新机械结构设计
    3. 增加机械臂功能实现
    4. 独立软硬件初始化函数
    5. 适配蓝牙及相关功能
    6. 优化抓放苹果时姿态准备方式
    7. 支持放置苹果
    8. 优化API拼写
    [6mm滑杆220mm.SLDPRT, 6mm滑杆230mm.SLDPRT, CameraSupport70VersionPart1.STL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]
2021-08-25 增加部分功能
    [TOFSuppter.STL, 机械臂.SLDASM, 舵机云台中心圆盘.SLDPRT]
2021-08-25 优化文件结构 适配升降式机械臂
2021-08-29 同步性更新
    0. 合并PWM库
    1. 更新部分Demo 完善部分逻辑
    [42步进支架.SLDPRT, 5转8联轴器.SLDPRT, 丝杆底支架.SLDPRT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]
2021-09-02 更新机械结构设计，更新部分demo，优化部分api，修复部分bug
    0. 更新K210端代码
    1. 更新机械结构设计
    2. 更新PWM库设计
    [3429电机.SLDPRT, 42步进.SLDPRT, 42步进40mm.SLDPRT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]
2021-10-01 更新：确定图像识别方案，优化部分机械设计，优化代码逻辑
    已知问题：
    机械设计图由于文件名冲突导致部分零件缺失
    [42步进35mm.SLDPRT, 摄像头支架.SLDPRT, 摄像头支架.STL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]
2021-10-02 增加从配置文件读取配置的功能
2021-10-12 优化图像识别app，实现linux下整体项目架构
    1. linux图像端支持串口数据收发
    2. linux图像端任务调度和框架实现
    + fix 9
    + fix 11
    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
    [摄像头支架.SLDPRT, 摄像头连接座.SLDPRT]
2021-10-14 支持升降台几何结算
    同步性更新
2021-10-16 修复BUG
    + fix #12
    + fix #10
    [Motor.c, RobotConfigs.h, SPI.c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]
2021-10-16 修复已知bug 优化程序效果 实现靶标识别
2021-10-23 删除LVGL依赖，修复大量bug，增加新特性
    [图像处理模块外壳上壳.SLDPRT, 图像处理模块外壳上壳.STL]
2021-11-24 更新软件架构、优化参数、优化机械设计
    1. 更新陈旧GPIO库依赖
    2. 优化图像识别参数
    3. 修复图像识别端buffer堆积的问题
    4. 更新图像参数调试方法
    5. 优化机械结构设计
    6. 增加机械臂平滑运动
    7. 规范enum相关拼写
    8. 修复升降台处理bug
    9. 暂时性修复Clock库毫秒延时bug（精度略微下降）
    10. 增加升降台苹果抓取，放置功能
    11. 优化API设计逻辑
    12. 修复FastMatch严重bug
    + fix #13
    [PCB1.PcbDoc, 图像处理模块外壳上壳.SLDPRT, 图像处理模块外壳上壳.STL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]
2021-11-25 优化API
    1. 更新Log库设计
    2. 更新版本管理
    3. 修复已知bug
    [RobotConfigs.h]
2022-01-14 完成Yolo v4 Tiny模型训练
    包含其他若干更新
    [PrivateConfigs.txt]
2022-01-14 优化git项目结构
2022-03-25 完成RKNN开发
2022-04-06 90分啦！！🎉🎉🎉
    剩下的15分也快要搞定了！
    还差水果识别并发送了
2022-04-08 满分了！🎉🎉🎉
    不过暂时还不能用于比赛
    还得再优化一些细节
2022-04-09 更新文档，更新机械部分外观设计
    [16齿同步轮.SLDPRT, 2020角件.SLDPRT, 2040角件.SLDPRT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]
2022-04-16 排名第一！整理文档
    [yolo-fastest.cfg]
2022-04-30 修复部分编译错误，整理上位机资料。
2022-04-30 更新文档
2022-05-24 更新获奖证书
    TODO: 整理工具HSV_Range
2022-05-24 更新HSV_Range工具
2022-05-24 拆分HSV_Range，更新文档。
2022-05-30 更新文档阅读体验
2022-05-30 优化文档阅读体验
2022-05-30 修复文档错误
2022-05-30 修复文档错误。
    已知问题：/ImageProcessing/RKNN/Environment/RK3328_env/
    并未上传
2022-05-30 添加PCB工程
    [PCB1.PcbDoc, PCB_Project.PrjPcb, PcbLib1.PcbLib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]
2022-05-30 优化文档

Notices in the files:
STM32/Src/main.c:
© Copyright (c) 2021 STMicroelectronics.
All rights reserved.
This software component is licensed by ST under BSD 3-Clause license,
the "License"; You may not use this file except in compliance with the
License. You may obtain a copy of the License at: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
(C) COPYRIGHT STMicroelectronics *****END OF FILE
